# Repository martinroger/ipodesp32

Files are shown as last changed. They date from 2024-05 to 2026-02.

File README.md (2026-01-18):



# iPodESP32 : an iPod emulator for 2nd gen Minis

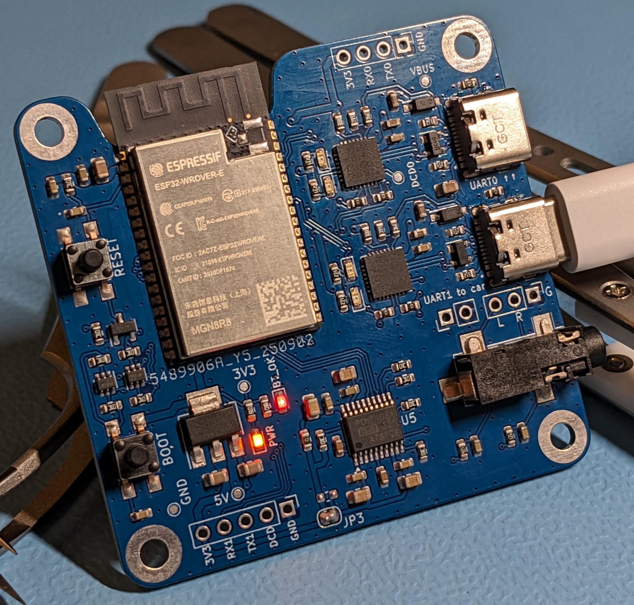
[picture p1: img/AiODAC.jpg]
AiO DAC board prototype


## CAVEAT
> [!WARNING]
> At the time of this commit, it has become apparent that the all CP2102 chips are not born equal. The hack consisting of spoofing a PL2303HX by overwriting the PID and VID on a CP2102 **only works on older versions**. I haven't yet managed to get it to work on CP2102N or CP2102-GM transceivers. Additionally, I haven't managed to get this hack to work on CP2104 or FTDI232R transceivers. For the time being, I would recommend holding off from ordering boards based on the designs in PCB unless you are certain you can source pre-2018 CP2102 chips.
> Work is happening on finding a solution, as the PL2303TA that would be the ideal candidate is hard to find in stock too.
> 
> **I may have found a practical solution by getting an ESP32S3 to spoof being a PL2303HX. Release v1.0.0 will introduce that solution !**

## Summary (TL;DR)

Second generation Minis (R56, R57, R58...) did not come with Bluetooth music streaming unless the Visual Boost or Mini Connected navigation option was selected (which wasn't hugely popular). 
Some of the later Minis (usually called LCI, or facelift Mini) started shipping with iPod support in the form of an USB receptacle, a 3.5mm AUX input and a special "Y-Cable". 

This repository is an attempt at bridging that gap with an ESP32 and a bag of tricks to provide **BT music streaming, retaining track data on the display and radio/steering wheel playback controls.**

## What is needed

Aside from a [Mini with a compatible radio head unit](https://github.com/martinroger/ipodesp32/wiki/How-to-identify-compatible-Minis) : 

- For the [full-DIY build](https://github.com/martinroger/ipodesp32/wiki/DIY-DAC%E2%80%90based-solution-(UDA1334A)) :
  - An ESP32 (not S3!) that has Bluetooth Classic or EDR support
  - A DAC (UDA1334 or PCM5102) breakout board
  - A CP2102 ~~or CP2104~~ breakout board with exposed DCD pin (no CP2102N or CP2102GM)
  - Jumper wires
  - Possibly some smaller hardware (resistors, capacitors) and a soldering iron

- For the Sandwich Carrier Board build, [follow this article](https://github.com/martinroger/ipodesp32/wiki/Sandwich-Carrier-Board-build)
- For the ESP32 AudioKit Top Hat build, [follow this other article](https://github.com/martinroger/ipodesp32/wiki/AudioKit-and-Haut%E2%80%90de%E2%80%90Forme-board)
- For the fancy ones out there wanting a small ESP32 A1S Mini, [it's here](https://github.com/martinroger/ipodesp32/wiki/ESP32%E2%80%90A1S%E2%80%90Mini-build)
- For the fancy but alternative-minded ones who also want an All-In-One, [it's there](https://github.com/martinroger/ipodesp32/wiki/ESP32%E2%80%90AiO-build)

## Alternative solutions

Over the year, some companies (mostly in China) have developped similar devices, such as the ones sold by **[Bovee](https://a.co/d/5lkZTkV)** or **[Gitank](https://thegitank.com/products/gitank-bluetooth-5-0-aptx-hd-adapter-with-y-cable-for-bmw-and-mini-cooper-usb-aux-ipod-iphone-music-interface-300b)**. The general principle is the same : a BT speaker is running an A2DP profile, while sufficient iPod-like communication is performed with the Mini to make it think there is an actual iPod connected.

I have had a very mixed bag of results with those, and it appeared to be even worse when using an Android phone, as the Playback/Synchronisation/Metadata seemed to be mostly reserved to iPhone users. Playback controls were also hit-and-miss.

## The iPodESP32 solution

Beyond the lame name, the solution proposed here does the following :

- Emulates an iPod Classic 5 - the U2 edition to be precise
- Passes song metadata from the phone/tablet (**Android or iOs**... or even others ?) regardless of what is playing the songs (Spotify remains the most tested to this date)
- Enables direct playback control from the radio interface, including steering wheel controls if present
- Auto-reconnects on ignition on, auto-pauses on ignition off
- Auto-pause and passes to whichever handsfree solution is present in case of phone call
- Provides many different interfaces for debug logging... because surely I didn't catch all them bugs
- Does not require any permanent modification of the car

## External (essential) libraries used

Respect where is due to the underlying libraries needed for this to work : 
- [AudioTools](https://github.com/pschatzmann/arduino-audio-tools)
- [ESP32-A2DP library](https://github.com/pschatzmann/ESP32-A2DP)
- [Arduino Audio Driver](https://github.com/pschatzmann/arduino-audio-driver)

## How to use it, and some tips

Although it should be pretty straightforward at this stage, to use this, you need to connect the USB with the modified VID/PID to the USB receptacle of the car, and the audio jack to the AUX input (with a male-male stereo cable, for example).

In its default configuration, the controller will wait for an established BT connection to a phone before it starts signalling to the vehicle that it is available. This is only necessary the first time a phone is connected to it, in other cases the controller will try to auto-reconnect.

Once the controller has established connection with the phone, it starts the handshake process with the head unit, and if all is good the Aux and USB options in the "Mode" source selector of the head unit are replaced by an "iPod" option. This normally takes a few seconds if the controller was just connected, so re-check after 10s if the iPod option is not available.
If it still doesn't come up, in some occasions it is necessary to disconnect the USB cable, wait 5-10 seconds and reconnect it and wait for the BT pairing to go through (check your phone!).

The Mini will try to automatically start playback once the iPod option is selected. Depending on your phone configuration, it may automatically open your favourite music player and start playing. In some cases it might be necessary to manually open a music player for things to get started. At this stage the display should update with the track info.

When you leave the car, the USB gets shut down after about 2 minutes (no risks of draining the battery) and normally the Mini negotiates a playback pause as the ignition is turned off...

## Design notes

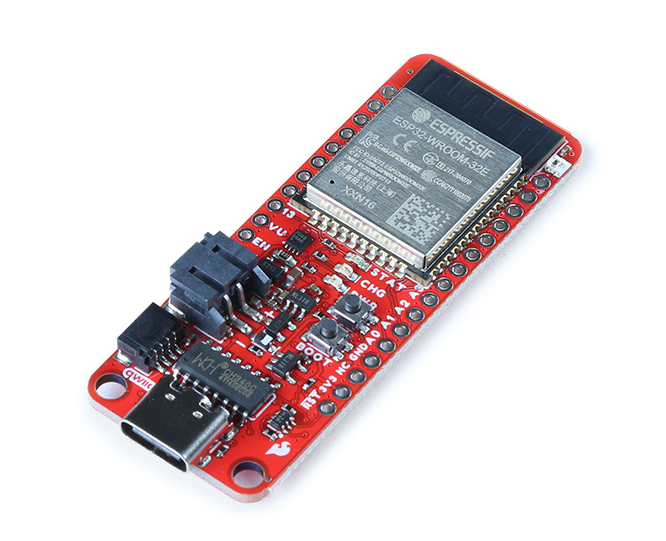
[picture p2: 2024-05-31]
img/SparkfunThingPlus.png

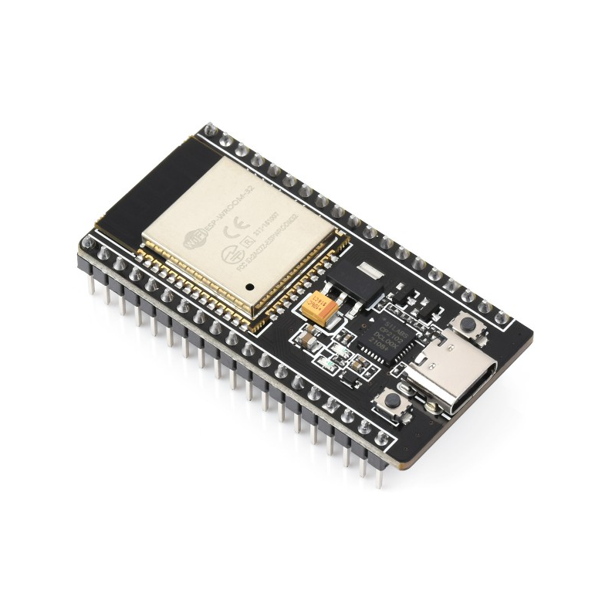
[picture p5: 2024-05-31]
img/nodeMCU32s.png

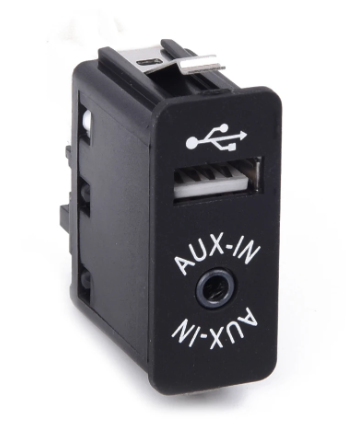
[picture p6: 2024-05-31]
img/usbAux.png

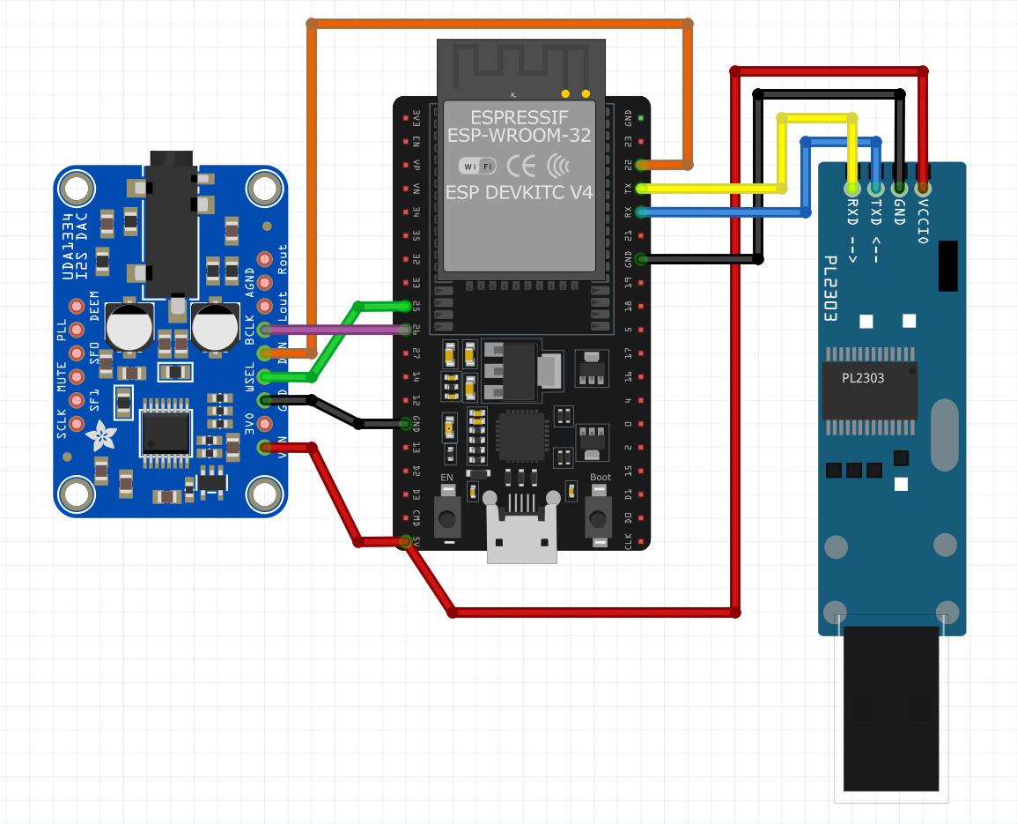
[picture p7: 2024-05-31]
img/routingDevKitCV4.png

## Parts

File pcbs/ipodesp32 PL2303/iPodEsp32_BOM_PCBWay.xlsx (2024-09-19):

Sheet: ipodesp32 PL2303
Reference | Value | Footprint | Datasheet | Description | Manufacturer_Name | Manufacturer_Part_Number | Mouser Part Number | Mouser Price/Stock | Qty
C1 | 4.7u | Capacitor_SMD:C_0603_1608Metric | https://mm.digikey.com/Volume0/opasdata/d220001/medias/docus/609/CL10A475KP8NNNC_Spec.pdf | CAP CER 4.7UF 10V X5R 0603 | Samsung Electro-Mechanics | CL10A475KP8NNNC |  |  | 1
C2 | 0.1u | Capacitor_SMD:C_0603_1608Metric | https://www.yageo.com/upload/media/product/productsearch/datasheet/mlcc/UPY-GPHC_X7R_6.3V-to-250V_24.pdf | CAP CER 0.1UF 16V X7R 0603 | Yageo | CC0603KRX7R7BB104 |  |  | 1
C3 | 10u | Capacitor_SMD:C_0805_2012Metric | https://connect.kemet.com:7667/gateway/IntelliData-ComponentDocumentation/1.0/download/datasheet/C0805C106K8PACTU | CAP CER 10UF 10V X5R 0805 | Kemet | C0805C106K8PAC7800 |  |  | 1
C4 | 1u | Capacitor_SMD:C_0603_1608Metric | https://mm.digikey.com/Volume0/opasdata/d220001/medias/docus/3584/CL10B105KP8NNNC_Spec.pdf | CAP CER 1UF 10V X7R 0603 | Samsung Electro-Mechanics | CL10B105KP8NNNC |  |  | 1
D1-D3 | 2.1V | LED_SMD:LED_0603_1608Metric | https://mm.digikey.com/Volume0/opasdata/d220001/medias/docus/858/LTST-C190GKT.pdf | LED GREEN CLEAR CHIP SMD | Lite-On Inc. | LTST-C190GKT |  |  | 3
IC1 | PL2303GS | SamacSys_Parts:SOIC127P600X170-8N |  | SOP-8_150mil USB ICs | Prolific | PL2303GS |  |  | 1
IC2 | 3678 | SamacSys_Parts:3678 | https://cdn-learn.adafruit.com/downloads/pdf/adafruit-i2s-stereo-decoder-uda1334a.pdf | Audio IC Development Tools Adafruit I2S Stereo Decoder - UDA1334A | Adafruit | 3678 |  |  | 1
J1 | USB_A | Connector_USB:USB_A_CNCTech_1001-011-01101_Horizontal | https://www.cnctech.us/pdfs/1001-011-01101_.pdf | CONN PLUG USB1.1 TYPEA 4P SMD RA | CNC Tech | 1001-011-01101 |  |  | 1
J2 | Conn_01x19_Pin | Connector_PinHeader_2.54mm:PinHeader_1x19_P2.54mm_Vertical | ~ |  |  |  |  |  | 1
J3 | Conn_01x05_Pin | Connector_PinHeader_2.54mm:PinHeader_1x05_P2.54mm_Vertical | ~ |  |  |  |  |  | 1
JP1 | TXD Route | Jumper:SolderJumper-3_P1.3mm_Bridged12_Pad1.0x1.5mm | ~ |  |  |  |  |  | 1
JP2 | RXD Route | Jumper:SolderJumper-3_P1.3mm_Bridged12_Pad1.0x1.5mm | ~ |  |  |  |  |  | 1
R2-R4 | 1K | Resistor_SMD:R_0603_1608Metric | https://www.yageo.com/upload/media/product/products/datasheet/rchip/PYu-RC_Group_51_RoHS_L_12.pdf | RES 1K OHM 1% 1/10W 0603 | Yageo | RC0603FR-071KL |  |  | 3
R5, R6 | 22 | Resistor_SMD:R_0603_1608Metric | https://www.yageo.com/upload/media/product/products/datasheet/rchip/PYu-RC_Group_51_RoHS_L_12.pdf | RES 22 OHM 1% 1/10W 0603 | Yageo | RC0603FR-0722RL |  |  | 2
U1 | ESP32-DevKitC | Espressif:ESP32-DevKitC | https://docs.espressif.com/projects/esp-idf/zh_CN/latest/esp32/hw-reference/esp32/get-started-devkitc.html |  |  |  |  |  | 1

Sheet: Sheet1
 |  |  | xxxx xxxx xxxxx xxPCS BOM (Sample Bill of Materials)
Item # | *Designator | *Qty | Manufacturer | *Mfg Part # | Description / Value | *Package/Footprint | Type | Your Instructions / Notes
1 | C1 | 1 | Samsung Electro-Mechanics | CL10A475KP8NNNC | CAP CER 4.7UF 10V X5R 0603 | Capacitor_SMD:C_0603_1608Metric | SMD
2 | C2 | 1 | Yageo | CC0603KRX7R7BB104 | CAP CER 0.1UF 16V X7R 0603 | Capacitor_SMD:C_0603_1608Metric | SMD
3 | C3 | 1 | Kemet | C0805C106K8PAC7800 | CAP CER 10UF 10V X5R 0805 | Capacitor_SMD:C_0805_2012Metric | SMD
4 | C4 | 1 | Samsung Electro-Mechanics | CL10B105KP8NNNC | CAP CER 1UF 10V X7R 0603 | Capacitor_SMD:C_0603_1608Metric | SMD
5 | D1-D3 | 3 | Lite-On Inc. | LTST-C190GKT | LED GREEN CLEAR CHIP SMD | LED_SMD:LED_0603_1608Metric | SMD
6 | IC1 | 1 | Prolific | PL2303GS | SOP-8_150mil USB ICs | SamacSys_Parts:SOIC127P600X170-8N | SMD
7 | J1 | 1 | CNC Tech | 1001-011-01101 | CONN PLUG USB1.1 TYPEA 4P SMD RA | Connector_USB:USB_A_CNCTech_1001-011-01101_Horizontal | DNS | DO NOT SOLDER, please supply
8 | R2-R4 | 3 | Yageo | RC0603FR-071KL | RES 1K OHM 1% 1/10W 0603 | Resistor_SMD:R_0603_1608Metric | SMD
9 | R5, R6 | 2 | Yageo | RC0603FR-0722RL | RES 22 OHM 1% 1/10W 0603 | Resistor_SMD:R_0603_1608Metric | SMD

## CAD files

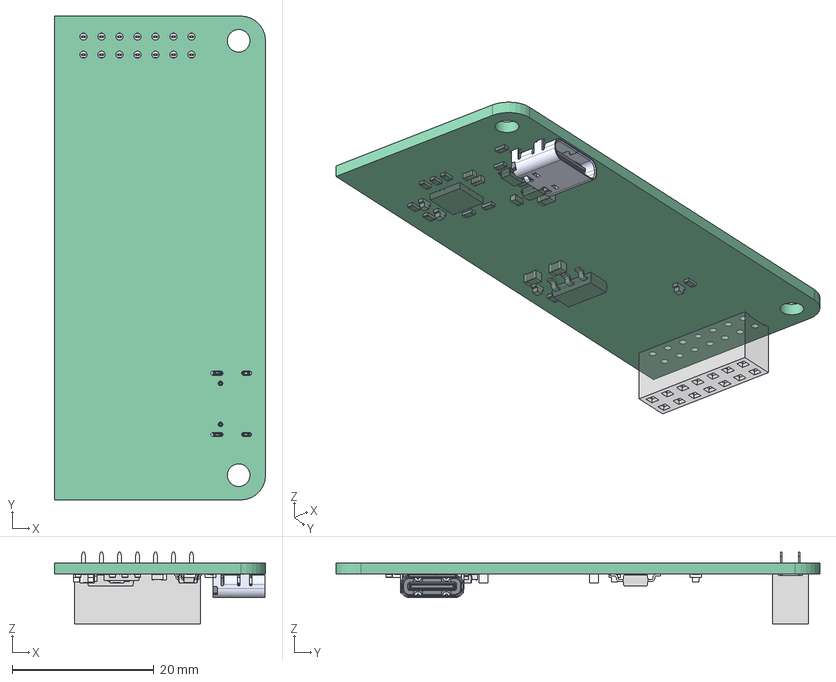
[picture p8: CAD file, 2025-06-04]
pcbs/hautDeForme/hautDeForme-hautDeForme.step
29.8 x 68.3 x 10.1 mm
Pcb_adfa
C14_C_0603_1608Metric_466b06563dad x 3
C6_C_0805_2012Metric_36fd2068b96d x 3
R26_R_0603_1608Metric_7708bdc434fe x 12
D9_LED_0603_1608Metric_46d654ef8e3e x 4
J1_PinSocket_2x07_P254mm_Vertical_6ab3e544b67c
U2_SOT_223_cc65569aa0fe
U4_QFN-28-1EP_5x5mm_Pitch0.5mm_e0a1b5ef8927
D14_D_SOD_123_b6459e2e886b
USB4105GFA_USB4105GFA
USB4105GFA_USB4105GFA001
USB4105GFA_USB4105GFA002
USB4105GFA_USB4105GFA003
USB4105GFA_USB4105GFA004
USB4105GFA_USB4105GFA005
USB4105GFA_USB4105GFA006
USB4105GFA_USB4105GFA007
USB4105GFA_USB4105GFA008
USB4105GFA_USB4105GFA009
USB4105GFA_USB4105GFA010
USB4105GFA_USB4105GFA011
USB4105GFA_USB4105GFA012
USB4105GFA_USB4105GFA013
USB4105GFA_USB4105GFA014
USB4105GFA_USB4105GFA015
USB4105GFA_USB4105GFA016
USB4105GFA_USB4105GFA017
USB4105GFA_USB4105GFA018
USB4105GFA_USB4105GFA019
USB4105GFA_USB4105GFA020
USB4105GFA_USB4105GFA021
USB4105GFA_USB4105GFA022
USB4105GFA_USB4105GFA023
USB4105GFA_USB4105GFA024
USB4105GFA_USB4105GFA025
USB4105GFA_USB4105GFA026
USB4105GFA_USB4105GFA027
USB4105GFA_USB4105GFA028
USB4105GFA_USB4105GFA029
USB4105GFA_USB4105GFA030
USB4105GFA_USB4105GFA031
USB4105GFA_USB4105GFA032
USB4105GFA_USB4105GFA033
USB4105GFA_USB4105GFA034
USB4105GFA_USB4105GFA035
USB4105GFA_USB4105GFA036
USB4105GFA_USB4105GFA037
USB4105GFA_USB4105GFA038
USB4105GFA_USB4105GFA039
USB4105GFA_USB4105GFA040
USB4105GFA_USB4105GFA041
USB4105GFA_USB4105GFA042
USB4105GFA_USB4105GFA043
D8_SOT_143_8c8184d03dee

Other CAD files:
pcbs/hautDeForme/hautDeForme.FCStd
pcbs/legacy boards/hautDeForme/hautDeForme.FCStd

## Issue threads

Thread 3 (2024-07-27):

PL2303 non-Gx are difficult to find and have the wrong PID

martinroger, 2024-07-27:
PL2303 Serial chips have become difficult to find. The latest variant this project is based upon, the PL2303Gx hasa different product ID (PID) of 23A3 and therefore is not recognized by the Boost CD unit.

Workarounds involve either rewriting the PID on the OTPRom (it works) or using a different chipset that has also an overwritable VID/PID.

martinroger, 2024-08-28:
Solution potentially found with the SiLab CP2102. Spoofing the VID and PID to look like a PL2303HX works, somehow !

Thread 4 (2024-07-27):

When skipping to the next song, the track info is not updated until the next skip

martinroger, 2024-07-27:
When actively skipping, the track info is not updated unless another fwd skip is requested OR the "Track" button is pressed.
Automatic change is not impacted

martinroger, 2024-08-28:
Will be addressed by specific PR

APF-MRoger, 2024-09-13:
Fixed in 50ea877a67728276d68b7e3371425ac8521d2902 initially but it broke the PREV/NEXT flip flopping because of a misconception around the prevXXX properties of espod and performing unjustified comparisons to try and determine NEXT/PREV moves when triggered from the phone.

First cleaned fix to be tested in ad4c92ea65b2d87a1674b790854c9f8f80d46cca

martinroger, 2024-09-19:
Pending Ack until new metadata seems to work OK. Fixed officially in 719ab09c6c69dd3a6eb89c550ffffab03b6c3533

Closed 2024-09-19.

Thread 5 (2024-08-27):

prevXXX character arrays for metadata are not updated

APF-MRoger, 2024-08-27:
prevXXX arrays are used for comparison but actually never updated so the comparison remains moot.

APF-MRoger, 2024-09-13:
prevXXX standalone arrays deprecated.
prevXXX property arrays of espod now used as a "previously playing track" info holders in case of rapid-firing requests during mini-triggered track changes.
**NO COMPARISON TO ASSESS IF THERE IS A SPONTANEOUS FWD/RWD TRACK CHANGE ANYMORE**

First official clean commit would be ad4c92e .

APF-MRoger, 2024-09-16:
Comparisons on prevXXX property arrays are now removed in 308ae70 so this issue should be closed.

Closed 2024-09-16.

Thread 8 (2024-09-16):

Track change using SetCurrentTrack need to be inhibited when there is a trackChangeAckPending

APF-MRoger, 2024-09-16:
When trackChangeAckPending is live, it is possible to still react to another current track change request. It might be necessary to inhibit those commands if there is a trackChangeAckPending when the command is received.

Also the trackChangeAckPending timeout should be reduced

martinroger, 2024-09-16:
trackChangeAckPending timeout shows that it should be doable in less than 600ms. However the 1100ms is still comfortable.

martinroger, 2024-09-19:
Issue seems irrelevant or a rare edge case. Closing for now.

Closed 2024-09-19.

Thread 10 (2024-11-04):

Receive and assess audiokit / ESP32 A1S board

martinroger, 2024-11-04:
Receive the Audiokit board, perform the following checks :

- [x] Flash via pins
- [x] Codec present on the board
- [x] UART interface VID/PID reprogrammability
- [ ] #15

martinroger, 2024-11-15:
- Codec is Es8388V1
- UART interface for UART0 is a Silabs CP2102. Checking if flashable via header.

martinroger, 2024-11-17:
To check :

- [ ] TX **and** RX capability of spoofed CP2102
- [ ] SD Card logging in appropriate branch. Resources : https://github.com/cyberman54/ESP32-Paxcounter/blob/master/src/sdcard.cpp

martinroger, 2024-11-26:
SD Card logging is proving to be an issue. SD card updating is OK.

Closed 2024-11-27.

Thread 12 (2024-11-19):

Move to pioarduino as other projects

martinroger, 2024-11-19:
There could be remnant issues with using the outdated framework. Move to https://github.com/pioarduino/platform-espressif32/releases/download/51.03.07/platform-espressif32.zip or 51.03.06

Closed 2024-11-27.

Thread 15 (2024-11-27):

SD Card local log implementation

martinroger, 2024-11-27:
Logging internal logs to the SD card is proving difficult as this is based on the Arduino framework. Plans are to move to IDF at some stage and use Arduino as components

Closed 2024-11-30.

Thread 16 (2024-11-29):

Loss of incoming Serial traffic after a few minutes

martinroger, 2024-11-29:
Using a CP2102 spoofing the VID/PID, incoming serial traffic seems sometimes lost. Not clear if SW or HW issue.

martinroger, 2024-11-29:
Indirectly related to #3 ?
To do :

- [ ] Check with actual PL2303HX if the incoming Rx is lost at HW or SW level, using a USB-UART bridge (FZero ?)
- [ ] Scan VIDs and PIDs to see which ones does the mini respond to with Serial
- [ ] Check the documentation for the PL2303HX Serial over USB implementation ? Same for the CP2102.

martinroger, 2024-12-04:
Communication still lost with genuine external PL2303HX on Serial0. Alternative ideas :

- [ ] Extend play_pos notification interval to 10s
- [ ] Refactor packet sender to use only one write()
- [ ] Async play_pos serial notification out of notification
- [ ] Use alternative Serial on 19-22
- [ ] No SD + GPIO15 muting ROM bootloader

martinroger, 2025-01-29:
Some improvements in commit e49873f1153c51d0e834b5febe3ff3d66e971a00 which partially links #24 and #23 to this.

Increasing the polling time seems to generally make things more stable, suggesting multiple things :

- At 19200 baud, with a 8N1 configuration, it takes 10 bit/transferred bytes. Practically this means that it's roughly a transfer time of 0.5ms/byte, not counting necessary breaks. In practice it must be slower than that. Setting a refresh polling rate of 5ms meant that there could be collisions on the output of the TX function if called in two places at the same time. Additionally it probably over-polls the incoming Serial for any message longer than 10 bytes (which can happen reasonably often). **Serial silence is golden !**
- AVRC and A2DP callbacks are reasonably high priority (15), Serial calls are in theory highest (24) but are contained in functions that are inheriting from `loop()`, which is lowest (1). Meaning it is possible that it stretches the inter-byte time, or even worse, starts weaving Serial flushes in-between one another.

There are still some issues at 50ms interval rate, and this is untested with AVRC/A2DP notifications.

One solution could be to manipulate the methods of the espod class to have higher priorities, however this would just mumble the interactions. It is preferrable to proceed like follows :

- Two FreeRTOS Queues : one for RX messages to be processed, populated by a relatively low priority listener Task (lower than 15) as the Serial Buffer is large enough and it can be interrupted, and another Queue for TX function, which is higher priority in order not to be interrupted (but lower polling rate), like 50ms minimum.
- One RX task as above that progressively consolidates an incoming Buffer and eventually turns it into a message Queue.
- One Processing task that churns incoming RX messages in the rxQueue, and eventually releases new messages in the txQueue. It can be low priority but possibly not too low to avoid buffer clogging on the RX side. The question of Timer tasks has to be clarified, like the delayed Ack (possibly requiring semaphores or mutex)
- One -dumb- but uninterruptible TX task, that checks the TXQueue and sends what is in it. Possibly with multiple yields in and a mutex if it doesn't work.

Could it be possible with binary semaphores and mutexes instead of queues ? Probably, as the Serial buffer works a bit like a queue. Am I smart enough to make that happen ? I doubt it :D

martinroger, 2025-02-15:
Lots of gibberish in my previous analysis. Now able to run very aggressive timings with 144e74bca5b9c45a92b76c262e441f97527dc655 with good stability, **as long as the UART DCD signal is active (low) !**

In branch `[taskCtrl+asyncMeta+hrtbeat](https://github.com/martinroger/ipodesp32/compare/taskCtrl%2BasyncMeta%2Bhrtbeat)` we are trying to introduce a SW solution to avoid having to physically control the DCD pin because it is not easily accessible on the board itself, with commit 8962710bfd0159655eb789cc2ad41405db3dd8fd.

APF-MRoger, 2025-02-17:
The heartbeat trick does not work (or at least not if sent every 10s). The branch will be left in place but no further commit and will become stale.

martinroger, 2025-02-17:
Confirmed that DCD pin grounded on a CP2102 with spoofed PID and VID seems to work.

APF-MRoger, 2025-05-28:
Confirmed DCD trick **and bulking 5V capacitance** seems to work 99% of the time. Should be closed with #33 .

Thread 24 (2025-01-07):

Move Serial activity away from callbacks regarding notifications

martinroger, 2025-01-07:
Try flags to process information and send Serial only OUT of notification callbacks.

martinroger, 2025-01-21:
Commit 5871031230cd438b8592953082529b97171f3ab8 does not resolve the issue, and actually somehow breaks the metadata refresh.
Theory :

- SD logger calls to write might make it more unstable
- Possible conflict with the Serial calls to the head unit
- There is no control of the tasks/threads between the A2DP/AVRC, I2S, SD writes and the Serial writes. Could this be part of the disconnection issue. Might be interesting moving to a stricter Task/thread control to avoid mutual interrupts

martinroger, 2025-02-02:
Idea : use queue.

martinroger, 2025-02-15:
Getting ready for closure in #31

APF-MRoger, 2025-06-04:
Done with #33

Closed 2025-06-04.

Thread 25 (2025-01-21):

Implement stricter task partitioning between Serial and A2DP/I2S and SD

martinroger, 2025-01-21:
There is a potential concurrency issue between the Serial.xxx calls and the rest of the routines running in the back, including when the SD logger is activated. One solution is to make sure that Tasks are clearly assigned to Cores and clearly prioritised.

martinroger, 2025-02-15:
Tasks and Timers added in taskControl branch and its children. Ultimately this is unlikely to have been the issue, but rather a timeout from the Mini side. Trying two strategies now :
- Hard-grounding the DCD pin to ground (seems to work)
- Sending a dummy L0x00 request to the mini every 10s to see if it resets any timeout

Closed 2025-02-15.

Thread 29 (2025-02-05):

Queuing from Timer end callback creates a prohibited load

martinroger, 2025-02-05:
At the end of the timer, queuing to the txQueue creates a core panic.

APF-MRoger, 2025-02-05:
be937d030879a19a640b72b3dfd194285c192eaa for tentative fix, separate queue from ISR

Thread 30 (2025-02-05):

Double Ack after Ack Pending on track change if metadata has not come in fast enough

martinroger, 2025-02-05:
If new metadata has not cleared the trackChangeAckPending quickly enough and the timeout is triggered (1100ms currently) there can be an accidental double Ack. Here is an example :

```
[141115][I][esPod.cpp:1015] processLingo0x04(): [esPod] CMD 0x0029 PlayControl req: 0x03 vs playStatus: 0x01
[141125][I][esPod.cpp:1056] processLingo0x04(): [esPod] Prev. index 1 New index 0 Tracklist pos. 2 Pending Meta 1 Timestamp: 141125 --> EXPLICIT NEXT TRACK
[141141][I][esPod.cpp:1512] L0x04_0x01_iPodAck(): [esPod] Ack 0x06 to command 0x0029 Numfield: 1100
[141194][I][BluetoothA2DPSink.cpp:747] av_notify_evt_handler(): [BT_AV] Play position changed: 112628-ms
[141217][I][BluetoothA2DPSink.cpp:791] av_hdl_avrc_evt(): [BT_AV] AVRC passthrough rsp: key_code 0x4b, key_state 0
[141252][I][main.cpp:294] playStatusHandler(): [A2DP_CB] A2DP_NEXT
[141286][I][BluetoothA2DPSink.cpp:791] av_hdl_avrc_evt(): [BT_AV] AVRC passthrough rsp: key_code 0x4b, key_state 1
[142240][I][BluetoothA2DPSink.cpp:747] av_notify_evt_handler(): [BT_AV] Play position changed: 710-ms
[142254][I][esPod.cpp:1489] L0x04_0x01_iPodAck(): [esPod] Ack 0x00 to command 0x0029
[143274][I][BluetoothA2DPSink.cpp:747] av_notify_evt_handler(): [BT_AV] Play position changed: 1746-ms
[144327][I][BluetoothA2DPSink.cpp:747] av_notify_evt_handler(): [BT_AV] Play position changed: 2795-ms
[144736][I][BluetoothA2DPSink.cpp:747] av_notify_evt_handler(): [BT_AV] Play position changed: 3211-ms
[144806][I][BluetoothA2DPSink.cpp:796] av_hdl_avrc_evt(): [BT_AV] AVRC metadata rsp: attribute id 0x1, Intro feat. Stalley
[144817][I][main.cpp:182] avrc_metadata_callback(): [AVRC_CB] Title rxed, ACK pending, trackTitleUpdated to Intro feat. Stalley
[144831][I][BluetoothA2DPSink.cpp:796] av_hdl_avrc_evt(): [BT_AV] AVRC metadata rsp: attribute id 0x2, Flume, Stalley
[144843][I][main.cpp:149] avrc_metadata_callback(): [AVRC_CB] Artist rxed, ACK pending, artistNameUpdated to Flume, Stalley
[144856][I][BluetoothA2DPSink.cpp:796] av_hdl_avrc_evt(): [BT_AV] AVRC metadata rsp: attribute id 0x4, Flume (Deluxe Edition)
[144870][I][main.cpp:117] avrc_metadata_callback(): [AVRC_CB] Album rxed, ACK pending, albumNameUpdated to Flume (Deluxe Edition)
[144883][I][BluetoothA2DPSink.cpp:796] av_hdl_avrc_evt(): [BT_AV] AVRC metadata rsp: attribute id 0x40, 234146
[144895][I][main.cpp:219] avrc_metadata_callback(): [AVRC_CB] Duration rxed, ACK pending, trackDurationUpdated to 234146
[144908][I][main.cpp:247] avrc_metadata_callback(): [AVRC_CB] Artist+Album+Title+Duration +++ ACK Pending 0x29
        Pending duration: 0
[144922][I][esPod.cpp:1489] L0x04_0x01_iPodAck(): [esPod] Ack 0x00 to command 0x0029
[144932][I][main.cpp:250] avrc_metadata_callback(): [AVRC_CB] trackChangeAckPending reset to 0x00
[144942][I][main.cpp:256] avrc_metadata_callback(): [AVRC_CB] Artist+Album+Title+Duration : True -> False
```

martinroger, 2025-02-06:
Tentative fix in b8a9cb344ebcb970e56edc268eb22ed62d65b50d

Closed 2025-02-15.

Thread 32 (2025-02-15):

Design simplified Audiokit/LyraT board

martinroger, 2025-02-15:
Given that the large amount of peripherals on the Audiokit board are unused, maybe it would be better to copy a slimmed down version of the LyraT or AudioKit ?

martinroger, 2025-02-17:
Replaced by #34

Closed 2025-02-17.

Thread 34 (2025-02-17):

Create/modify PCBs to offer control of the DCD pin

martinroger, 2025-02-17:
- [x] Modify an AudioKit PCB
- [x] Create carrier board for "sandwich" implementation
- [x] Create standalone PCB

APF-MRoger, 2025-04-10:
Done in branch 32, will be integrated in #33

Closed 2025-04-10.

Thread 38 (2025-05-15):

Library compatibility tracking

APF-MRoger, 2025-05-15:
Commit 396cd43445c918b421badf7b288807d9891f2b66

OK :
|-- ESP32-A2DP @ 1.8.7+sha.b6a20dd
|-- audio-tools @ 1.1.0+sha.036645b
|-- audio-driver @ 0.1.2+sha.993248c

APF-MRoger, 2025-05-15:
Commit : 4e8b470e0b78374e47c078a42a8064976b8e7be9

OK :
|-- ESP32-A2DP @ 1.8.7+sha.f275b82
|-- audio-tools @ 1.1.1+sha.710fe3f
|-- audio-driver @ 0.1.3+sha.7c07c36

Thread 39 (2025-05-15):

Expose DCD pin as easy-to-solder pad

martinroger, 2025-05-15:
For non-BMW applications, it might be easier to expose the DCD pin as a through-hole pad.

APF-MRoger, 2025-05-26:
Done as of e5afc75e4cf8b15366bb625a20f870dff8392412

Closed 2025-05-26.

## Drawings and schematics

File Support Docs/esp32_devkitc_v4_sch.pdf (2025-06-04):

# ESP32 Module Power Supply

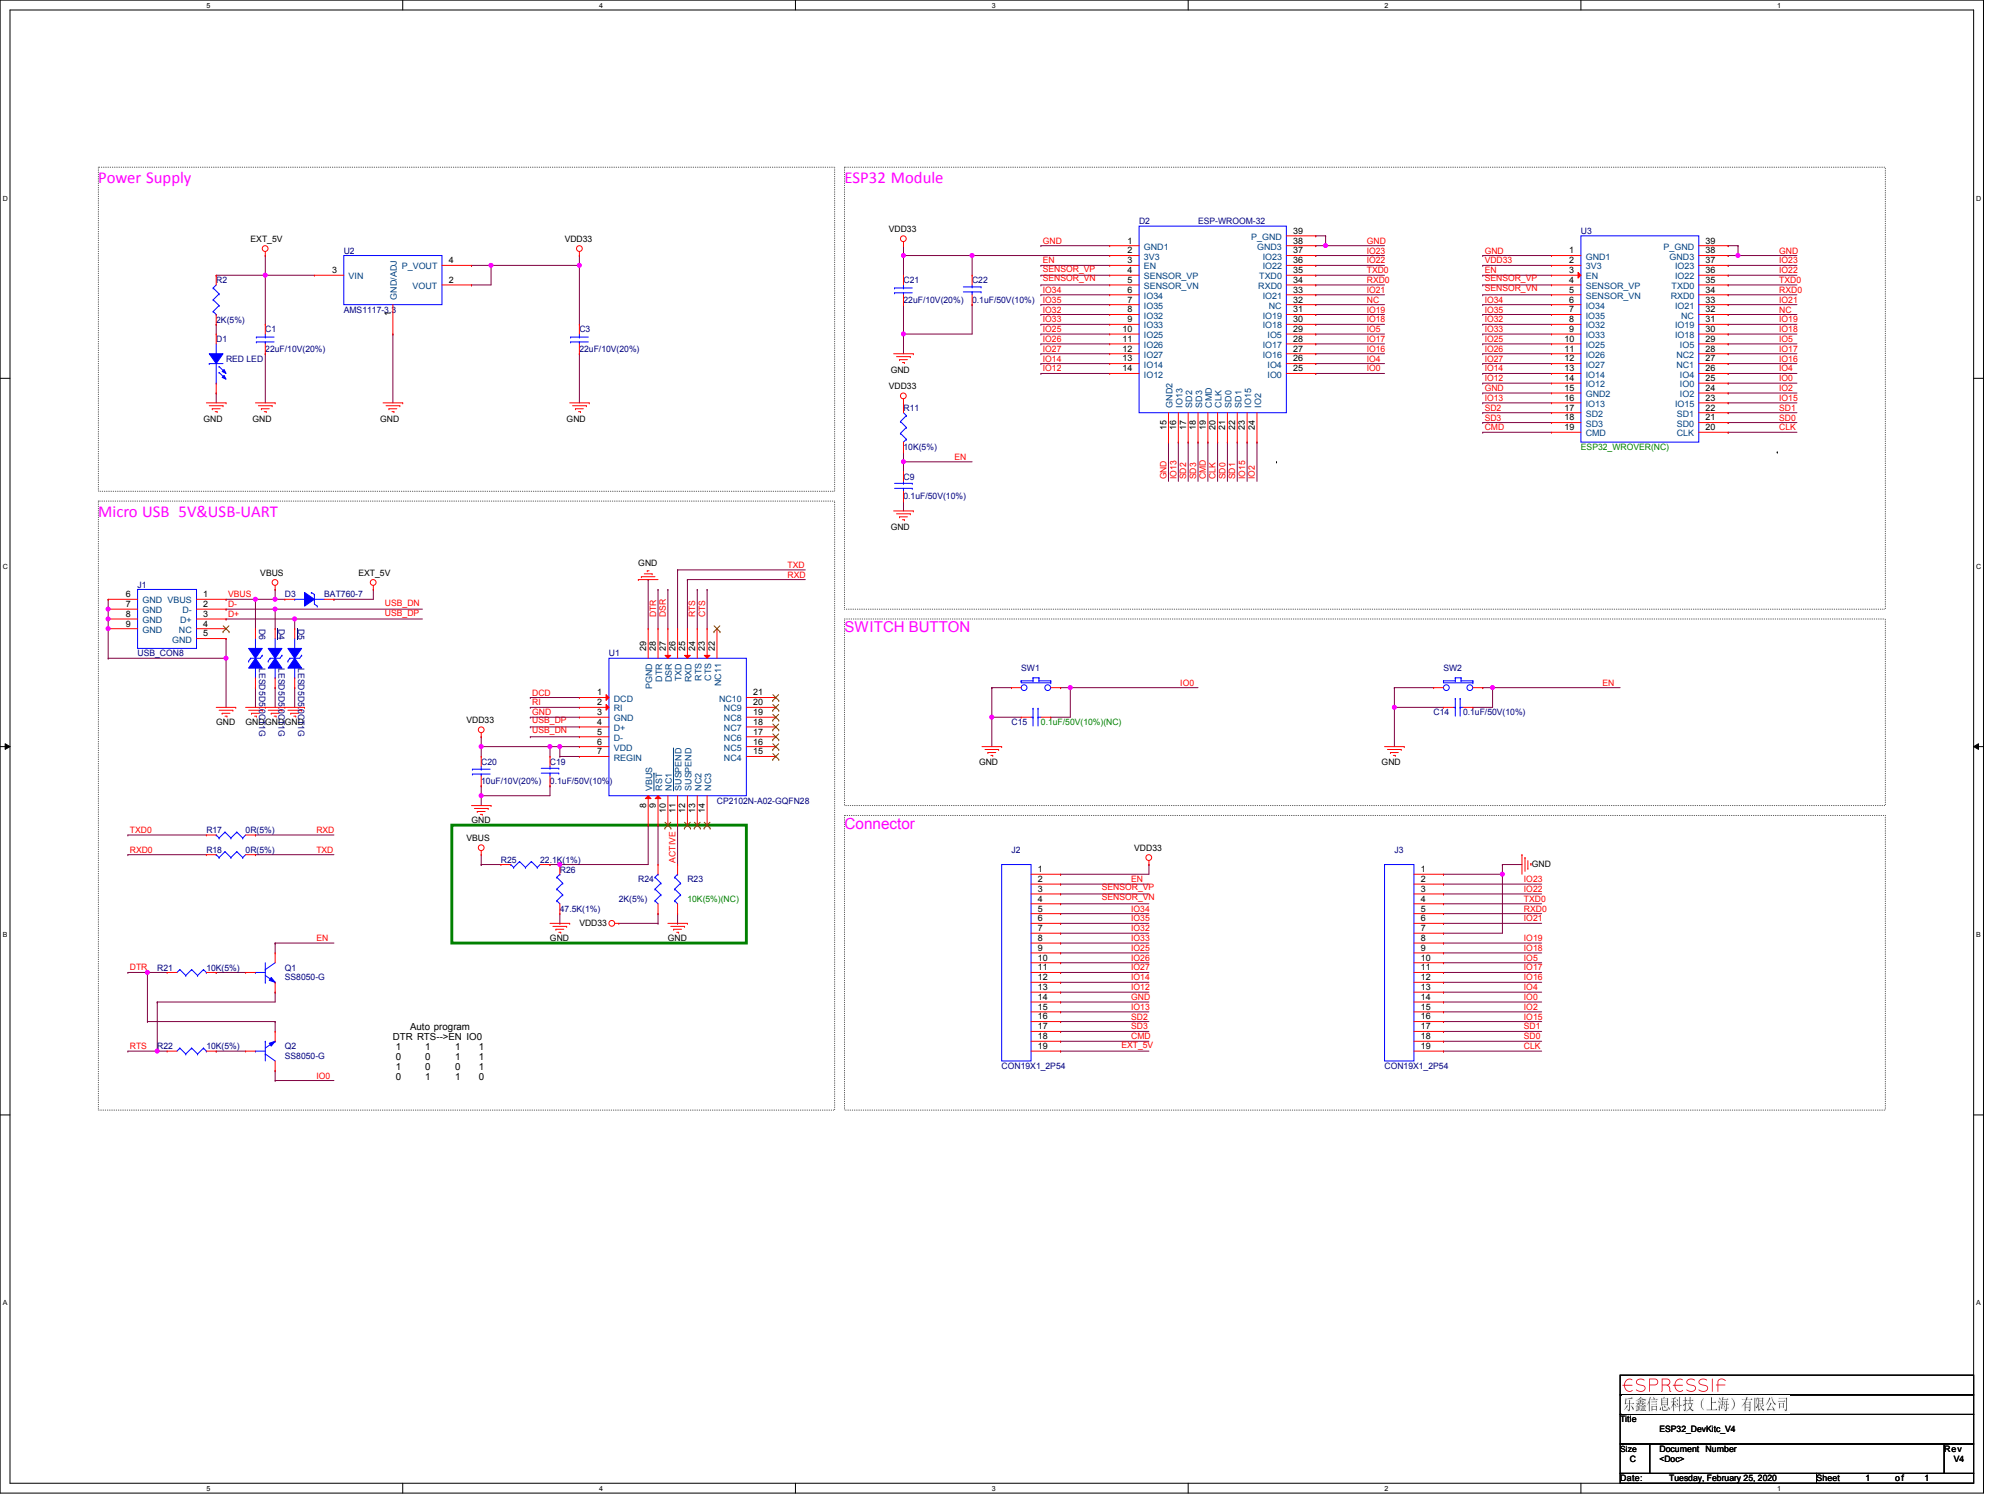
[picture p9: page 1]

Micro USB 5V&USB-UART

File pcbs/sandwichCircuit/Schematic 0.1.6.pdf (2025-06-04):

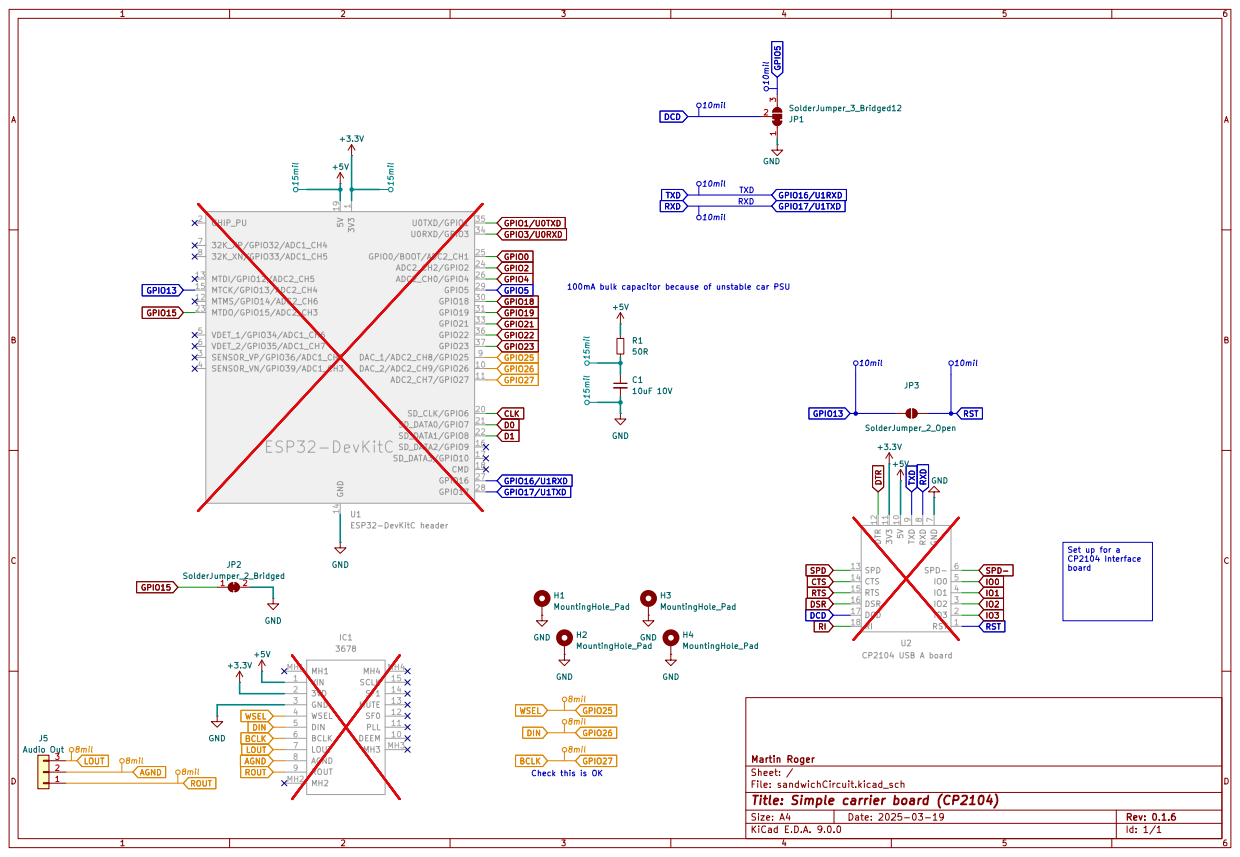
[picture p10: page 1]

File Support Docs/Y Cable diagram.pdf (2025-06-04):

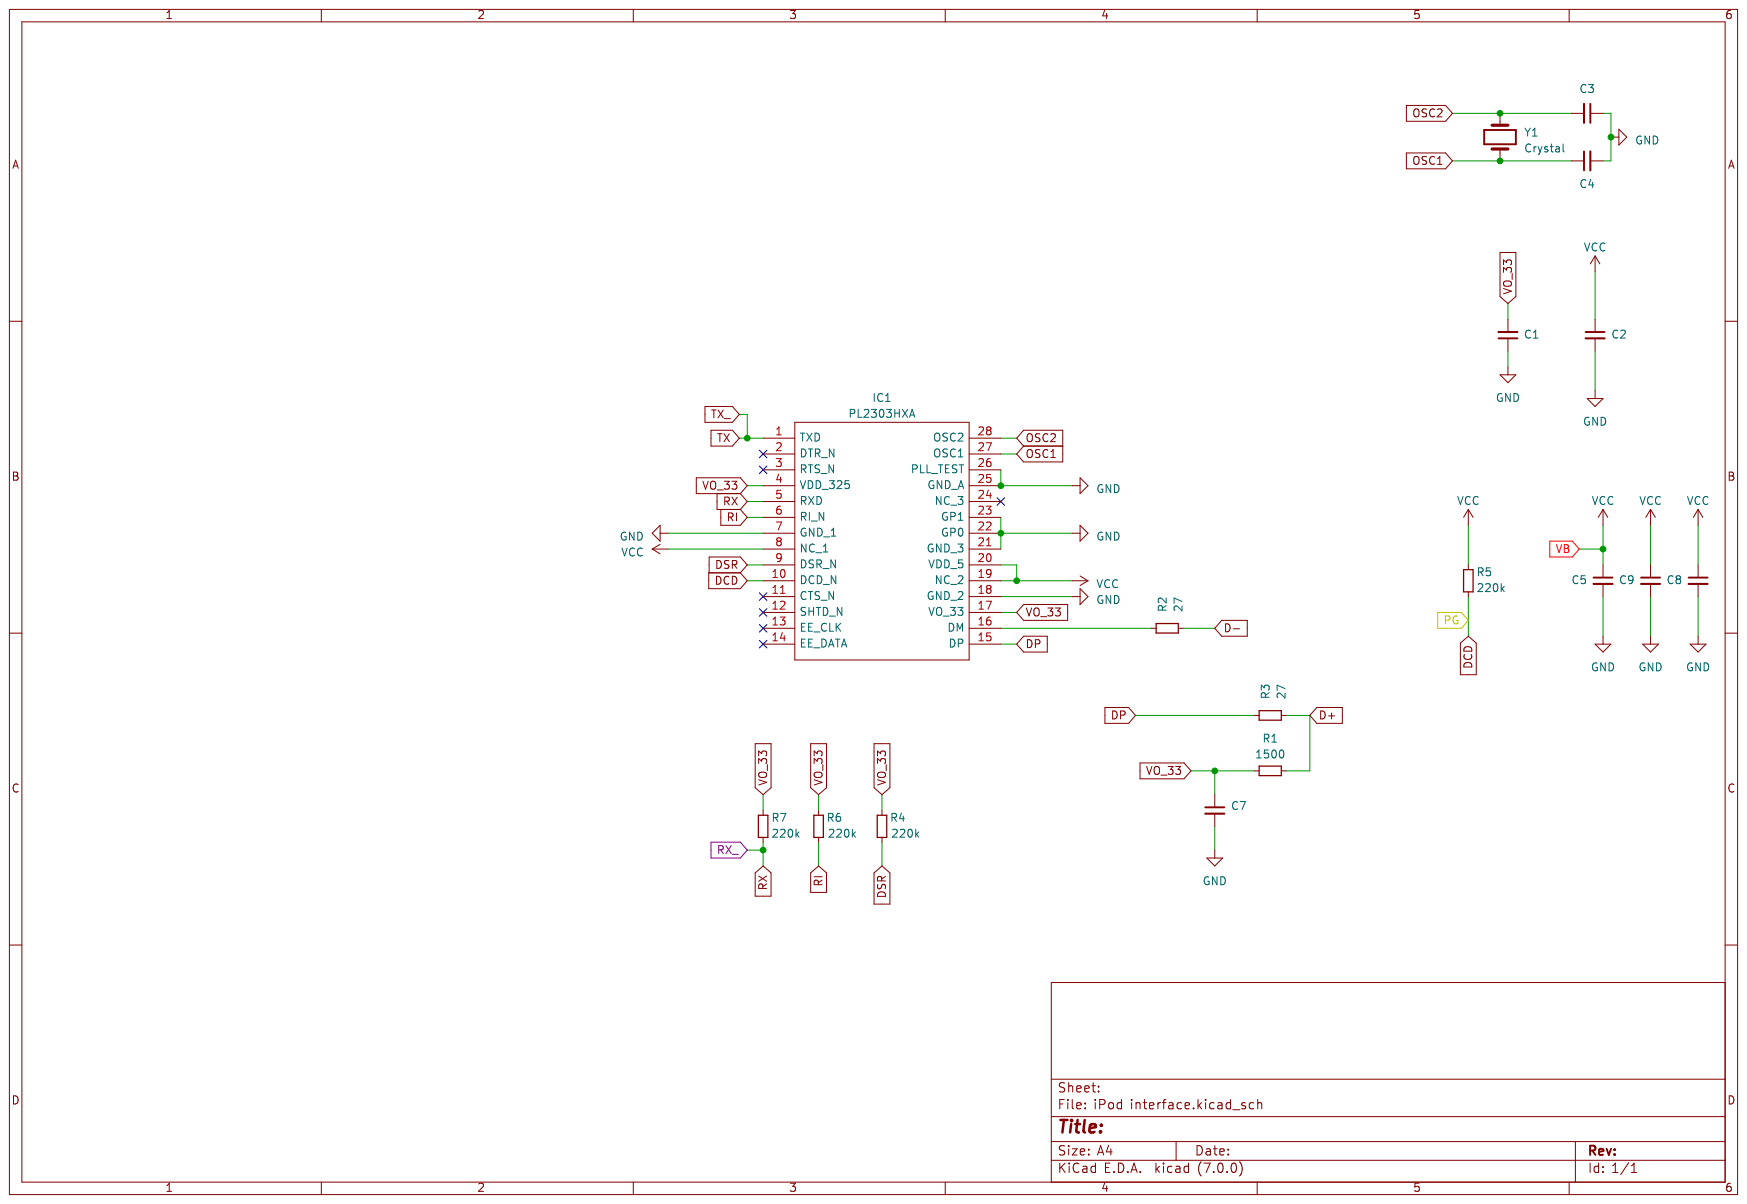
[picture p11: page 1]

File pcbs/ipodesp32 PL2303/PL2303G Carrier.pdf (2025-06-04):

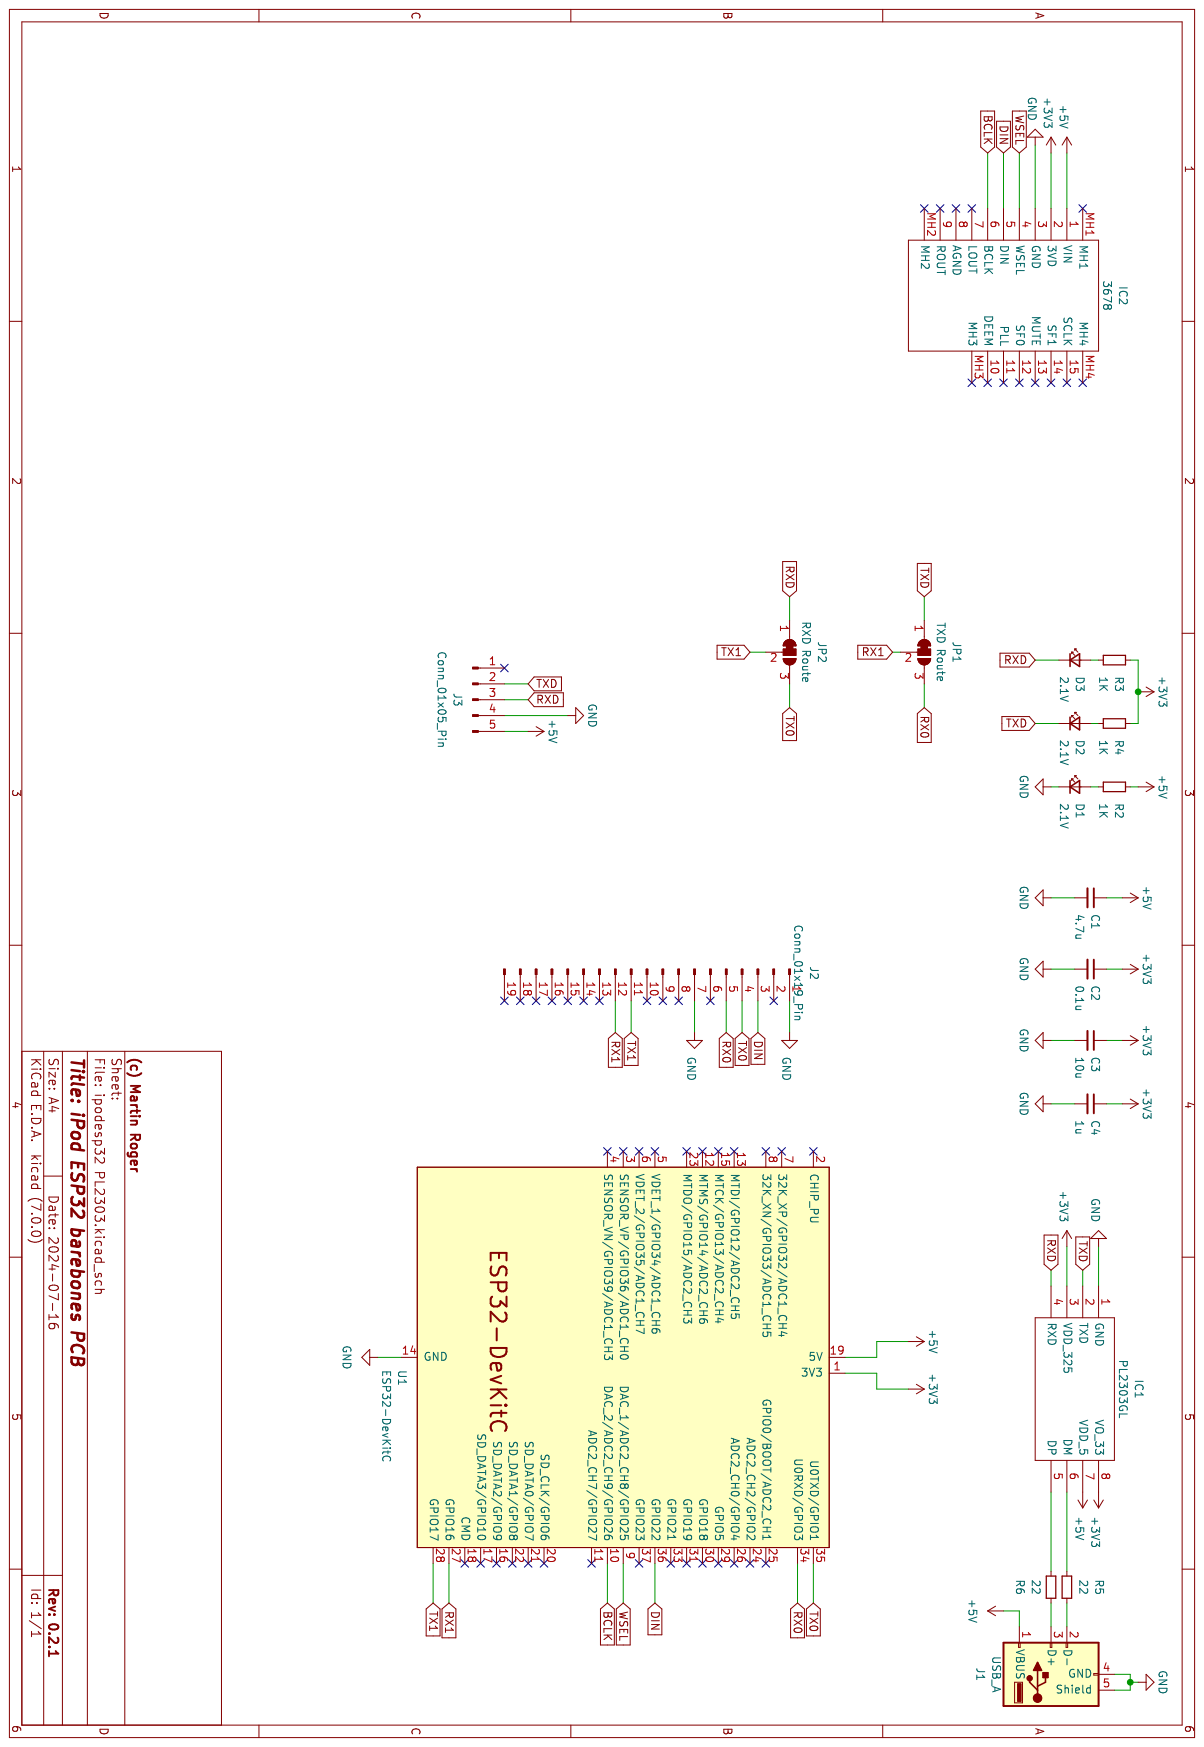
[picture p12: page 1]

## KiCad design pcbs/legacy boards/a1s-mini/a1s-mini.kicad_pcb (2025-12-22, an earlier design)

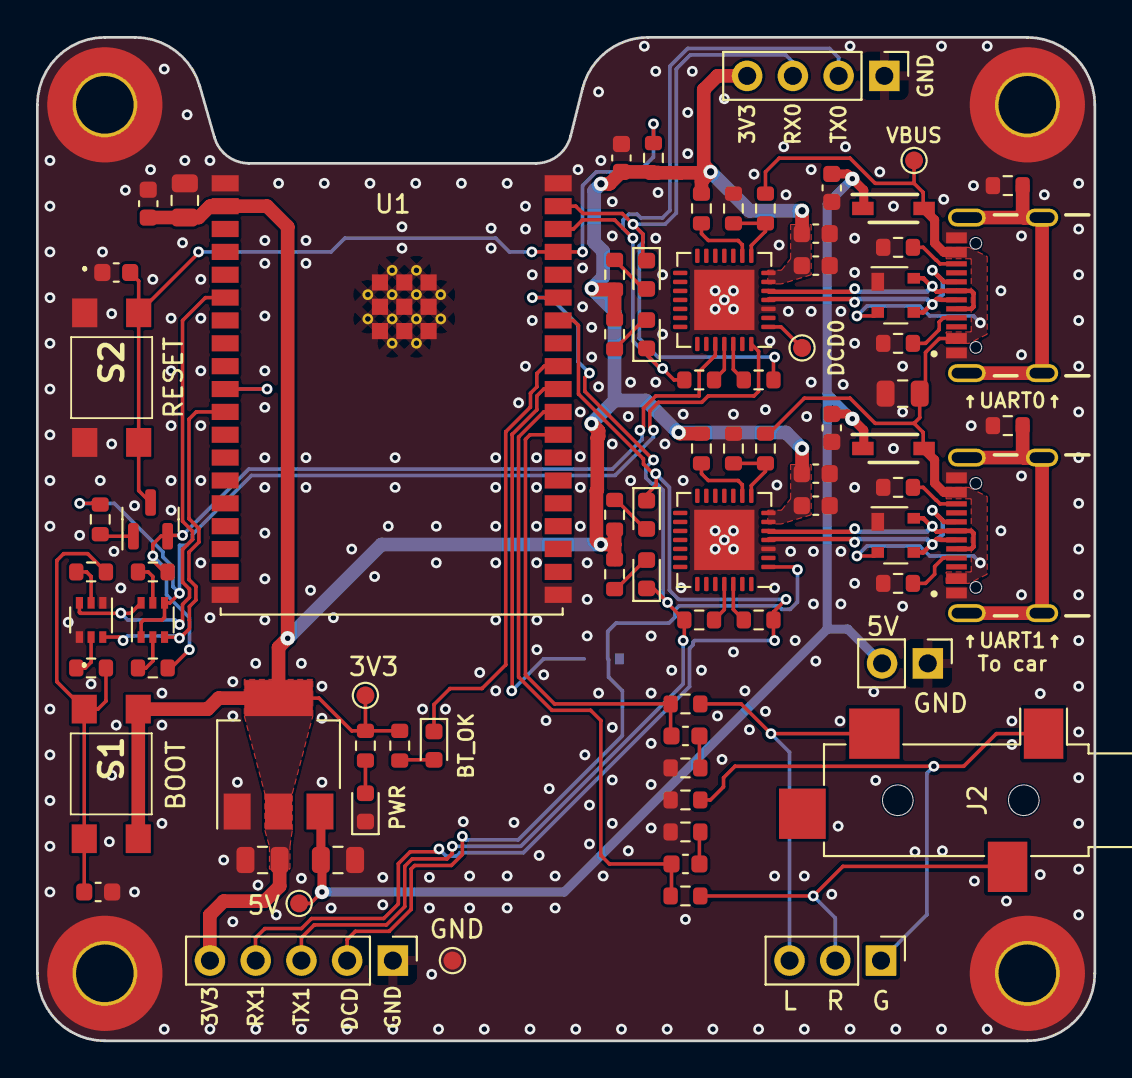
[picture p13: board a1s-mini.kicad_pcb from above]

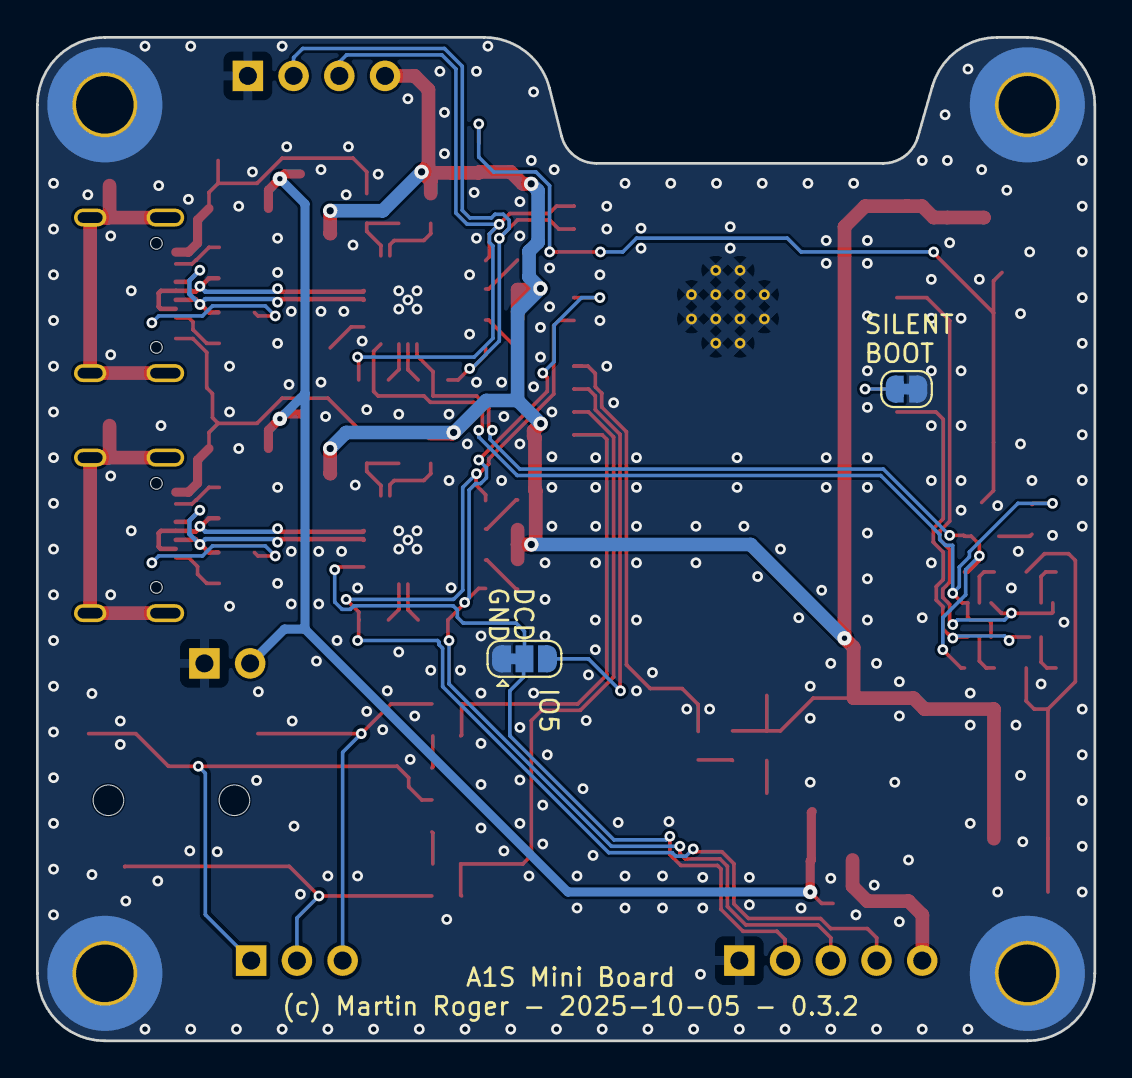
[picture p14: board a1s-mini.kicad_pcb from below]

Board: 2 copper layers, 58.8 x 55.7 mm, 86 parts (2 on the bottom side), 55 nets.

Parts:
3V1, 5V1: TestPoint_Small; TestPoint_Pad_D1.0mm
C1, C3, C4, C5, C8, C9, C11, C14: 0.1uF 50V; C_0603_1608Metric
C2, C6, C7, C16: 22uF 10V; C_0805_2012Metric
C10, C12, C13, C15: 10uF 10V; C_0603_1608Metric
D1, D2, D9, D11: 2.1V G 10mA; LED_0603_1608Metric
D5: 2.1V O 10mA; LED_0603_1608Metric
D6: 2V R 10mA; LED_0603_1608Metric
D7, D8: SP0503BAHTG; SOT-143
D10, D14: 1N5819HW-7-F; SOD3716X145N
DCD1: TestPoint_Small; TestPoint_Pad_D1.0mm
GND1: TestPoint_Small; TestPoint_Pad_D1.0mm
H1, H2, H3, H4: MountingHole_Pad; MountingHole_3.2mm_M3_Pad_TopBottom
J1: UART1; PinHeader_1x05_P2.54mm_Vertical
J2: SJ-3524-SMT-TR-PI; Jack_3.5mm_CUI_SJ-3524-SMT_Horizontal
J3: Audio Out; PinHeader_1x03_P2.54mm_Vertical
J4: UART0; PinHeader_1x04_P2.54mm_Vertical
J5, J6: USB4105-GF-A; GCT_USB4105-GF-A
J7: 5V; PinHeader_1x02_P2.54mm_Vertical
JP1: SolderJumper_3_Bridged12; SolderJumper-3_P1.3mm_Bridged12_RoundedPad1.0x1.5mm
JP2: SolderJumper_2_Bridged; SolderJumper-2_P1.3mm_Bridged_RoundedPad1.0x1.5mm
Q3: BC818; SOT-23
Q4, Q6: MBT3904DW1; SOT-363_SC-70-6
R1, R2, R5, R6, R34, R35: 1K 1%; R_0603_1608Metric
R7, R12, R13, R14, R32, R33: 10K 1%; R_0603_1608Metric
R8, R9: 22R 1%; R_0603_1608Metric
R10, R11, R18, R19, R21, R26, R27, R29, R31: 0R; R_0603_1608Metric
R15, R23: 22.1K 1%; R_0603_1608Metric
R16, R24: 47.5K 1%; R_0603_1608Metric
R17, R25: 2K 1%; R_0603_1608Metric
R20, R22, R28, R30: 5.1K 1%; R_0603_1608Metric
S1, S2: TL3305BF260QG
U1: ESP32 A1S; ESP32-A1S
U2: AZ1117CH-3.3TRG1; SOT-223-3_TabPin2
U3: CP2102N; QFN-28-1EP_5x5mm_P0.5mm_EP3.35x3.35mm
U4: CP2102-GM; QFN-28-1EP_5x5mm_P0.5mm_EP3.35x3.35mm
VBUS1: TestPoint_Small; TestPoint_Pad_D1.0mm

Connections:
+3.3V: 3V1.1, C1.2, C2.2, C3.2, C7.2, C10.2, C11.2, C13.2, C14.2, J1.5, J4.4, R1.1, R2.1, R5.1, R6.1, R7.1, R17.1, R25.1, R34.1, R35.1, S1.3, S1.4, U1.2 (3V3), U2.2 (VO), U3.6 (VDD), U3.7 (VREGIN), U4.6 (VDD), U4.7 (VREGIN)
+5V: 5V1.1, C6.2, C12.2, C15.2, D10.1, D14.1, J7.2, U2.3 (VI)
/CP2102N_0/D+: D7.3 (K), J5.A6 (DP1), J5.B6 (DP2), U3.4 (D+)
/CP2102N_0/D-: D7.4 (K), J5.A7 (DN1), J5.B7 (DN2), U3.5 (D-)
/CP2102N_0/DCD: DCD1.1, U3.1 (~DCD)
/CP2102_1/D+: D8.3 (K), J6.A6 (DP1), J6.B6 (DP2), U4.4 (D+)
/CP2102_1/D-: D8.4 (K), J6.A7 (DN1), J6.B7 (DN2), U4.5 (D-)
/CP2102_1/DCD: J1.2, JP1.2 (C), U4.1 (~DCD)
AGND: J2.S, J3.1, R31.1
DTR0: Q6.1 (E1), Q6.4 (E2), R12.1, U3.28 (~DTR)
EN: C8.2, Q3.3 (C), R7.2, S2.3, S2.4, U1.35 (EN)
GND: C1.1, C2.1, C3.1, C6.1, C7.1, C8.1, C9.1, C10.1, C11.1, C12.1, C13.1, C14.1, C15.1, C16.1, D5.1 (K), D7.1 (A), D8.1 (A), GND1.1, H1.1, H2.1, H3.1, H4.1, J1.1, J4.1, J5.A1_B12 (GND), J5.B1_A12 (GND__1), J6.A1_B12 (GND), J6.B1_A12 (GND__1), J7.1, JP1.1 (A), JP2.2 (B), Q4.1 (E1), Q4.4 (E2), R8.2, R9.2, R16.2, R20.1, R21.2, R22.2, R24.2, R28.1, R29.2, R30.2, R31.2, S2.1, S2.2, U1.1 (GND), U1.19 (GND), U1.20 (GND), U1.38 (GND), U1.39 (GND), U2.1 (GND), U3.3 (GND), U3.29 (GND), U4.3 (GND), U4.29 (GND)
HPOUTL: C4.2, R10.1, U1.27 (HPOUTL)
HPOUTR: C5.2, R11.1, U1.28 (HPOUTR)
IO0: Q4.3 (C2), Q6.6 (C1), U1.6 (IO0)
IO2: Q4.6 (C1), Q6.3 (C2), U1.11 (IO2)
IO5: JP1.3 (B), U1.29 (IO5)
IO18: D6.1 (K), U1.30 (IO18)
LOUT: J2.T, J3.3, R10.2
unnamed: C4.1, R8.1
unnamed: C5.1, R9.1
unnamed: C9.2, R32.1, R33.1, S1.1, S1.2
unnamed: D1.2 (A), R1.2
unnamed: D2.2 (A), R2.2
unnamed: D5.2 (A), R5.2
unnamed: D6.2 (A), R6.2
unnamed: D9.2 (A), R34.2
unnamed: D11.2 (A), R35.2
unnamed: J5.A5 (CC1), R20.2
unnamed: J5.B5 (CC2), R22.1
unnamed: J5.SH1 (SHELL_GND), J5.SH2 (SHELL_GND__1), J5.SH3 (SHELL_GND__2), J5.SH4 (SHELL_GND__3), R21.1
unnamed: J6.A5 (CC1), R28.2
unnamed: J6.B5 (CC2), R30.1
unnamed: J6.SH1 (SHELL_GND), J6.SH2 (SHELL_GND__1), J6.SH3 (SHELL_GND__2), J6.SH4 (SHELL_GND__3), R29.1
unnamed: JP2.1 (A), U1.10 (IO15)
unnamed: Q3.1 (B), R12.2
unnamed: Q4.2 (B1), R33.2
unnamed: Q4.5 (B2), R32.2
unnamed: Q6.2 (B1), R13.2
unnamed: Q6.5 (B2), R14.2
unnamed: R19.1, U3.25 (RXD)
unnamed: R18.1, U3.26 (TXD)
unnamed: R15.2, R16.1, U3.8 (VBUS)
unnamed: R17.2, U3.9 (~RST)
unnamed: R27.1, U4.25 (RXD)
unnamed: R26.1, U4.26 (TXD)
unnamed: R23.2, R24.1, U4.8 (VBUS)
unnamed: R25.2, U4.9 (~RST)
ROUT: J2.R, J3.2, R11.2
RTS0: Q3.2 (E), R13.1, R14.1, U3.24 (~RTS)
RXD0: D1.1 (K), J4.3, R18.2, U1.37 (RXD0)
RXD1: D9.1 (K), J1.4, R26.2, U1.32 (IO19)
TXD0: D2.1 (K), J4.2, R19.2, U1.36 (TXD0)
TXD1: D11.1 (K), J1.3, R27.2, U1.33 (IO22)
VBUS: C16.2, D7.2 (K), D8.2 (K), D10.2, D14.2, J5.A4_B9 (VBUS), J5.B4_A9 (VBUS__1), J6.A4_B9 (VBUS), J6.B4_A9 (VBUS__1), R15.1, R23.1, VBUS1.1

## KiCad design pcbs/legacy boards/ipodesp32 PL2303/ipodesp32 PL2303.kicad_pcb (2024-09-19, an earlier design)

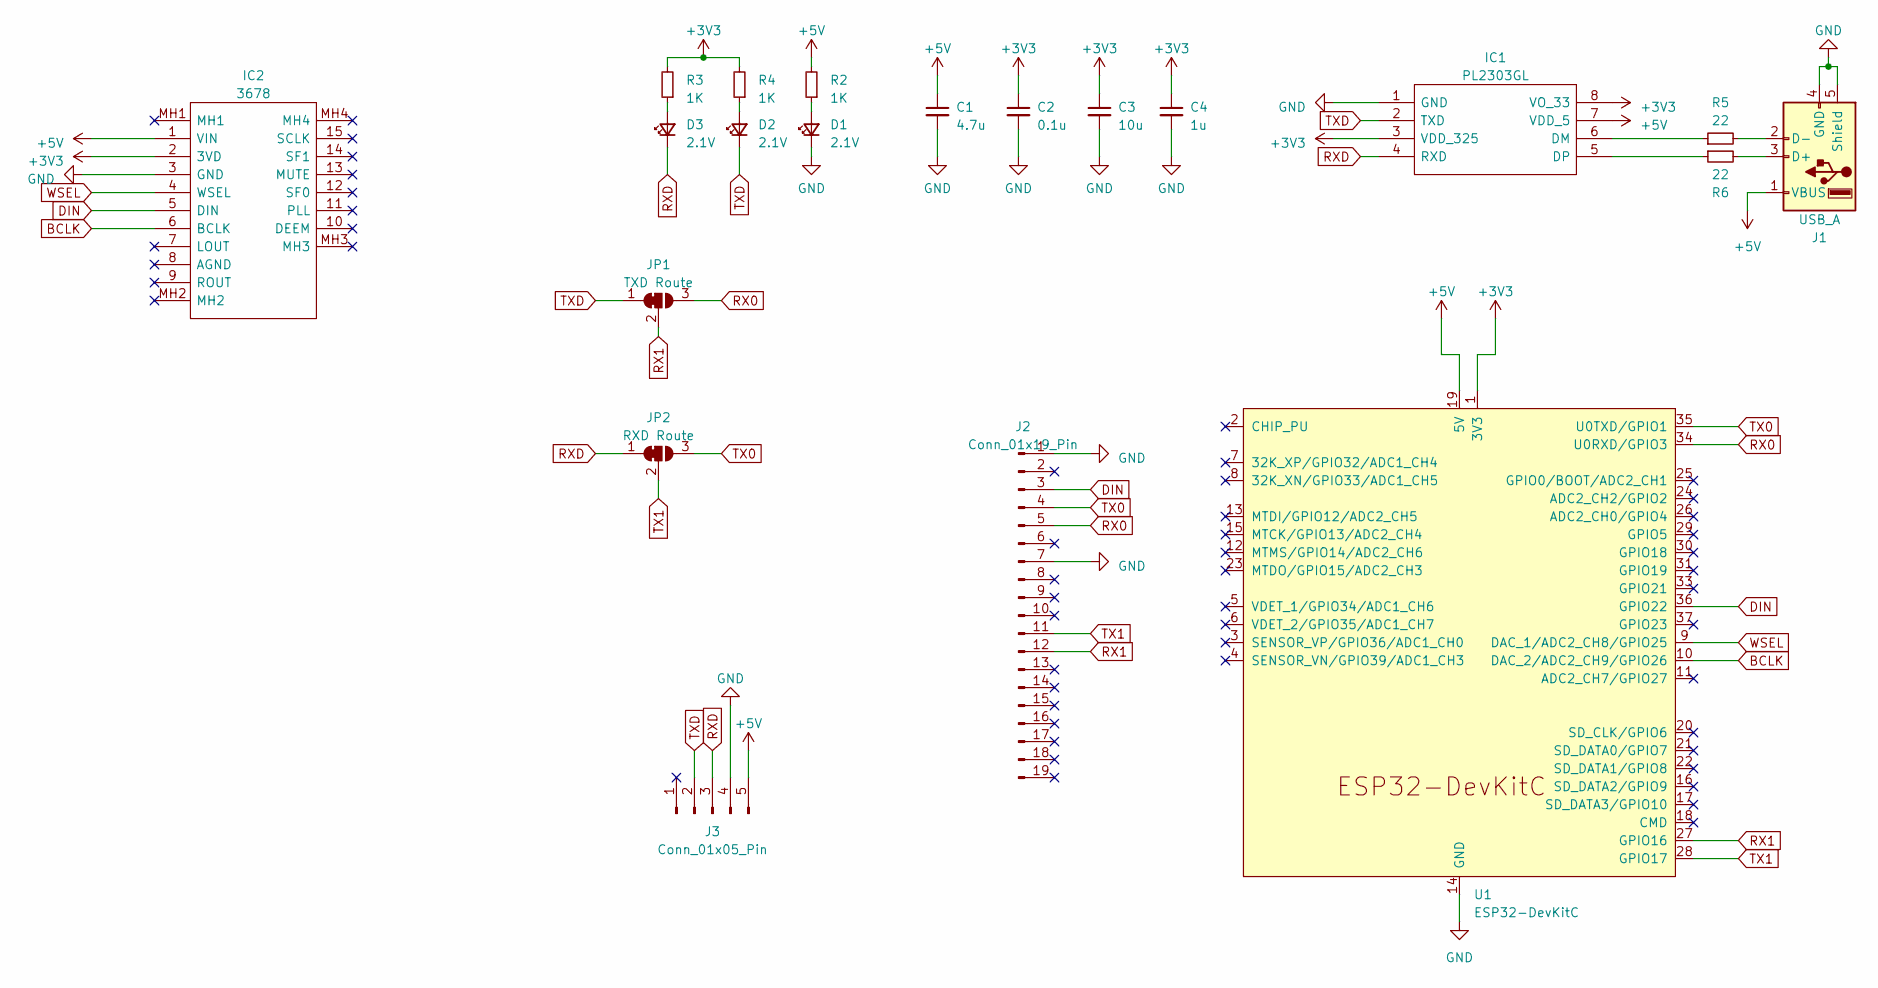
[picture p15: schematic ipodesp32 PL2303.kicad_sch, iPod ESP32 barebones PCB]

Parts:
C1: 4.7u; C_0603_1608Metric; Manufacturer_Part_Number CL10A475KP8NNNC
C2: 0.1u; C_0603_1608Metric; Manufacturer_Part_Number CC0603KRX7R7BB104
C3: 10u; C_0805_2012Metric; Manufacturer_Part_Number C0805C106K8PAC7800
C4: 1u; C_0603_1608Metric; Manufacturer_Part_Number CL10B105KP8NNNC
D1, D2, D3: 2.1V; LED_0603_1608Metric; Manufacturer_Part_Number LTST-C190GKT
IC1: PL2303GL; SOIC127P600X170-8N; Manufacturer_Part_Number PL2303GS
IC2: 3678; Manufacturer_Part_Number 3678
J1: USB_A; USB_A_CNCTech_1001-011-01101_Horizontal; Manufacturer_Part_Number 1001-011-01101
J2: Conn_01x19_Pin; PinHeader_1x19_P2.54mm_Vertical
J3: Conn_01x05_Pin; PinHeader_1x05_P2.54mm_Vertical
JP1: TXD Route; SolderJumper-3_P1.3mm_Bridged12_Pad1.0x1.5mm
JP2: RXD Route; SolderJumper-3_P1.3mm_Bridged12_Pad1.0x1.5mm
R2, R3, R4: 1K; R_0603_1608Metric; Manufacturer_Part_Number RC0603FR-071KL
R5, R6: 22; R_0603_1608Metric; Manufacturer_Part_Number RC0603FR-0722RL
U1: ESP32-DevKitC

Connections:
+3V3: C2.1, C3.1, C4.1, IC1.3 (VDD_325), IC1.8 (VO_33), IC2.2 (3VD), R3.2, R4.2, U1.1 (3V3)
+5V: C1.1, IC1.7 (VDD_5), IC2.1 (VIN), J1.1 (VBUS), J3.5, R2.2, U1.19 (5V)
BCLK: IC2.6 (BCLK), U1.10 (DAC_2/ADC2_CH9/GPIO26)
DIN: IC2.5 (DIN), J2.3, U1.36 (GPIO22)
GND: C1.2, C2.2, C3.2, C4.2, D1.1 (K), IC1.1 (GND), IC2.3 (GND), J1.4 (GND), J1.5 (Shield), J2.1, J2.7, J3.4, U1.14 (GND), U1.32 (GND), U1.38 (GND)
unnamed: D1.2 (A), R2.1
unnamed: D2.2 (A), R4.1
unnamed: D3.2 (A), R3.1
unnamed: IC1.6 (DM), R5.1
unnamed: IC1.5 (DP), R6.1
unnamed: J1.3 (D+), R6.2
unnamed: J1.2 (D-), R5.2
RX0: J2.5, JP1.3 (B), U1.34 (U0RXD/GPIO3)
RX1: J2.12, JP1.2 (C), U1.27 (GPIO16)
RXD: D3.1 (K), IC1.4 (RXD), J3.3, JP2.1 (A)
TX0: J2.4, JP2.3 (B), U1.35 (U0TXD/GPIO1)
TX1: J2.11, JP2.2 (C), U1.28 (GPIO17)
TXD: D2.1 (K), IC1.2 (TXD), J3.2, JP1.1 (A)
WSEL: IC2.4 (WSEL), U1.9 (DAC_1/ADC2_CH8/GPIO25)

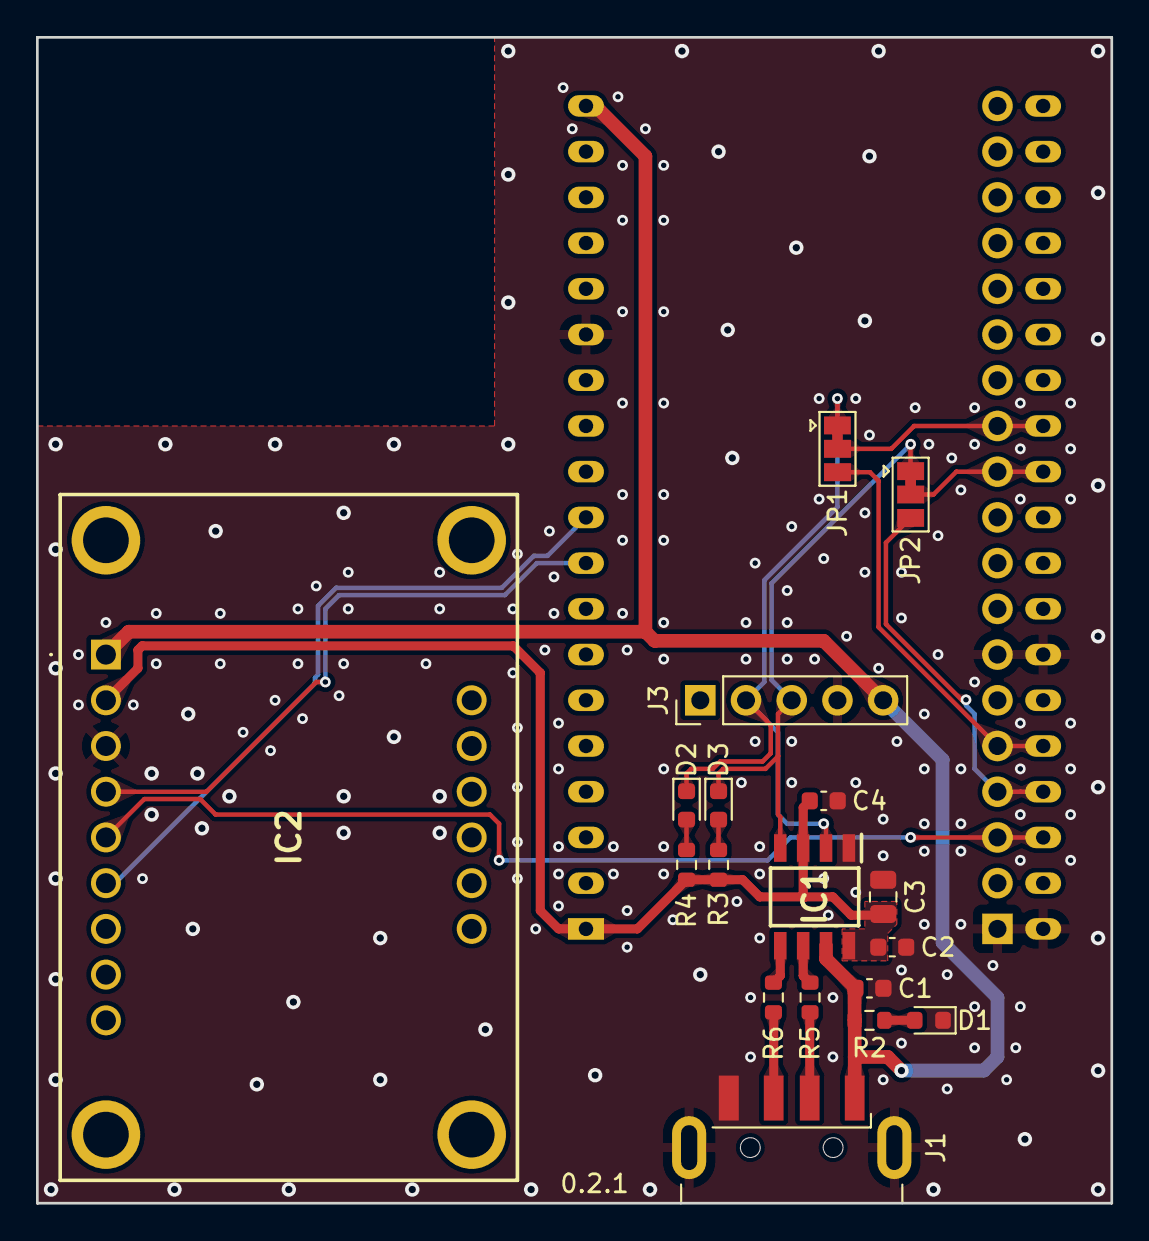
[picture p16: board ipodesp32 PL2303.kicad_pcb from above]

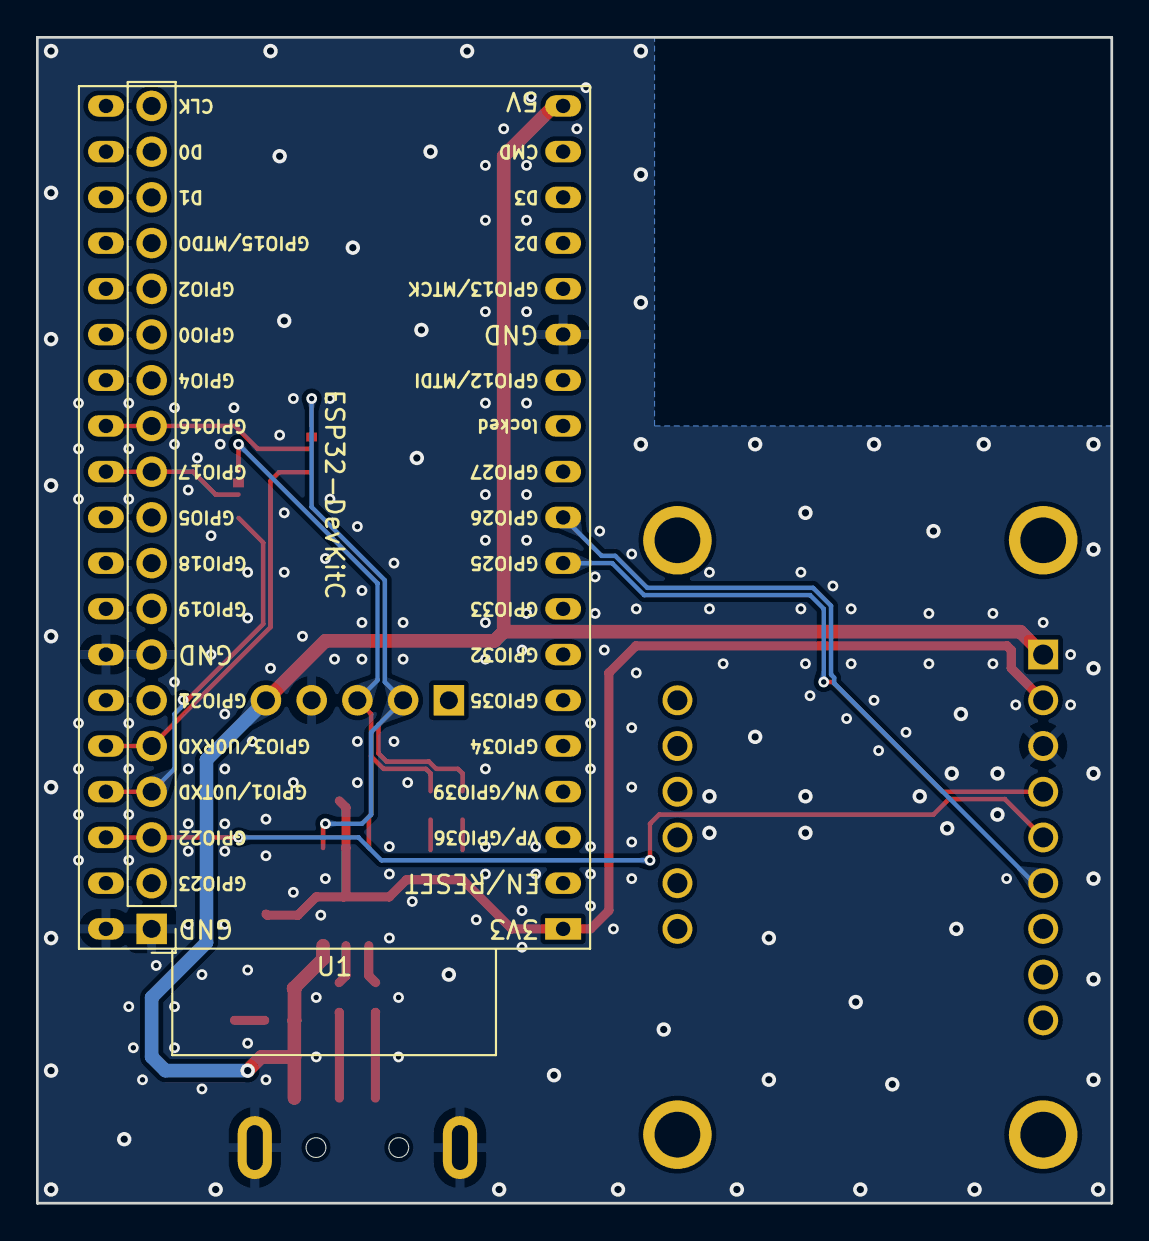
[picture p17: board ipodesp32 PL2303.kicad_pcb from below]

Board: 2 copper layers, 59.7 x 64.8 mm, 20 parts (2 on the bottom side), 19 nets.

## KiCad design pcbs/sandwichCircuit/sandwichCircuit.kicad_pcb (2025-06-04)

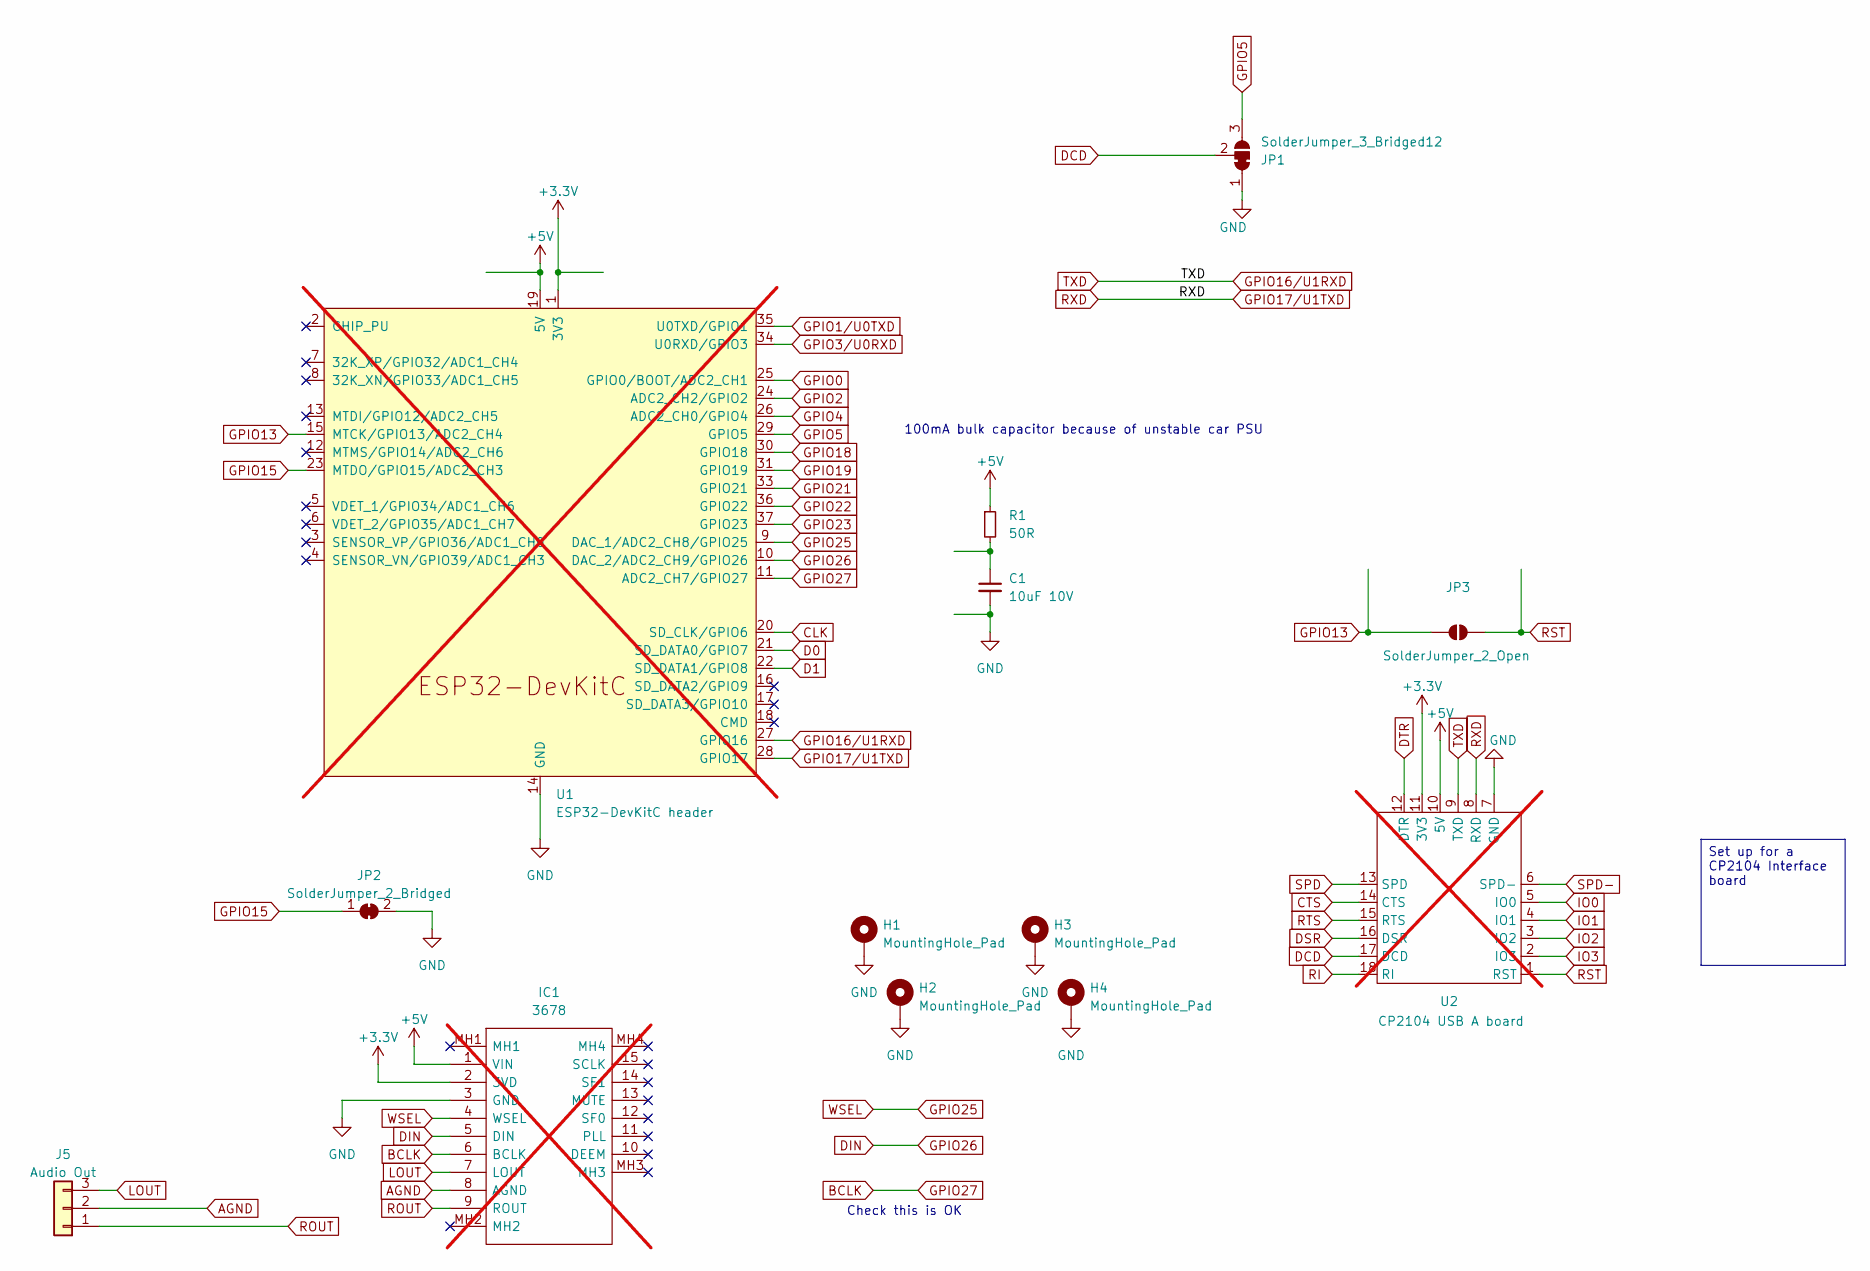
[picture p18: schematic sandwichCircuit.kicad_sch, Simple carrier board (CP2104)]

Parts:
C1: 10uF 10V; C_Radial_D5.0mm_H7.0mm_P2.00mm
H1, H2, H3, H4: MountingHole_Pad; MountingHole_3.2mm_M3_Pad_TopBottom
IC1: 3678; Manufacturer_Part_Number 3678; Mouser Part Number 485-3678; not fitted
J5: Audio Out; PinHeader_1x03_P2.54mm_Vertical
JP1: SolderJumper_3_Bridged12; SolderJumper-3_P1.3mm_Bridged12_RoundedPad1.0x1.5mm
JP2: SolderJumper_2_Bridged; SolderJumper-2_P1.3mm_Bridged_RoundedPad1.0x1.5mm
JP3: SolderJumper_2_Open; SolderJumper-2_P1.3mm_Open_RoundedPad1.0x1.5mm
R1: 50R; R_Axial_DIN0207_L6.3mm_D2.5mm_P10.16mm_Horizontal
U1: ESP32-DevKitC header; ESP32-DevKitC; not fitted
U2: CP2104 USB A board; CP2104_USB_Board; not fitted

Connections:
+3.3V: IC1.2 (3VD), U1.1 (3V3), U2.11 (3V3)
+5V: IC1.1 (VIN), R1.1, U1.19 (5V), U2.10 (5V)
AGND: IC1.8 (AGND), J5.2
BCLK: IC1.6 (BCLK), U1.11 (ADC2_CH7/GPIO27)
CLK: U1.20 (SD_CLK/GPIO6)
CTS: U2.14 (CTS)
D0: U1.21 (SD_DATA0/GPIO7)
D1: U1.22 (SD_DATA1/GPIO8)
DCD: JP1.2 (C), U2.17 (DCD)
DIN: IC1.5 (DIN), U1.10 (DAC_2/ADC2_CH9/GPIO26)
DSR: U2.16 (DSR)
DTR: U2.12 (DTR)
GND: C1.2, H1.1, H2.1, H3.1, H4.1, IC1.3 (GND), JP1.1 (A), JP2.2 (B), U1.14 (GND), U1.32 (GND), U1.38 (GND), U2.7 (GND)
GPIO0: U1.25 (GPIO0/BOOT/ADC2_CH1)
GPIO1/U0TXD: U1.35 (U0TXD/GPIO1)
GPIO2: U1.24 (ADC2_CH2/GPIO2)
GPIO3/U0RXD: U1.34 (U0RXD/GPIO3)
GPIO4: U1.26 (ADC2_CH0/GPIO4)
GPIO5: JP1.3 (B), U1.29 (GPIO5)
GPIO13: JP3.1 (A), U1.15 (MTCK/GPIO13/ADC2_CH4)
GPIO15: JP2.1 (A), U1.23 (MTDO/GPIO15/ADC2_CH3)
GPIO16/U1RXD: U1.27 (GPIO16), U2.9 (TXD)
GPIO17/U1TXD: U1.28 (GPIO17), U2.8 (RXD)
GPIO18: U1.30 (GPIO18)
GPIO19: U1.31 (GPIO19)
GPIO21: U1.33 (GPIO21)
GPIO22: U1.36 (GPIO22)
GPIO23: U1.37 (GPIO23)
GPIO25: IC1.4 (WSEL), U1.9 (DAC_1/ADC2_CH8/GPIO25)
IO0: U2.5 (IO0)
IO1: U2.4 (IO1)
IO2: U2.3 (IO2)
IO3: U2.2 (IO3)
LOUT: IC1.7 (LOUT), J5.3
unnamed: C1.1, R1.2
RI: U2.18 (RI)
ROUT: IC1.9 (ROUT), J5.1
RST: JP3.2 (B), U2.1 (RST)
RTS: U2.15 (RTS)
SPD: U2.13 (SPD)
SPD-: U2.6 (SPD-)

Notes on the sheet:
100mA bulk capacitor because of unstable car PSU
Check this is OK
Set up for a CP2104 Interface board

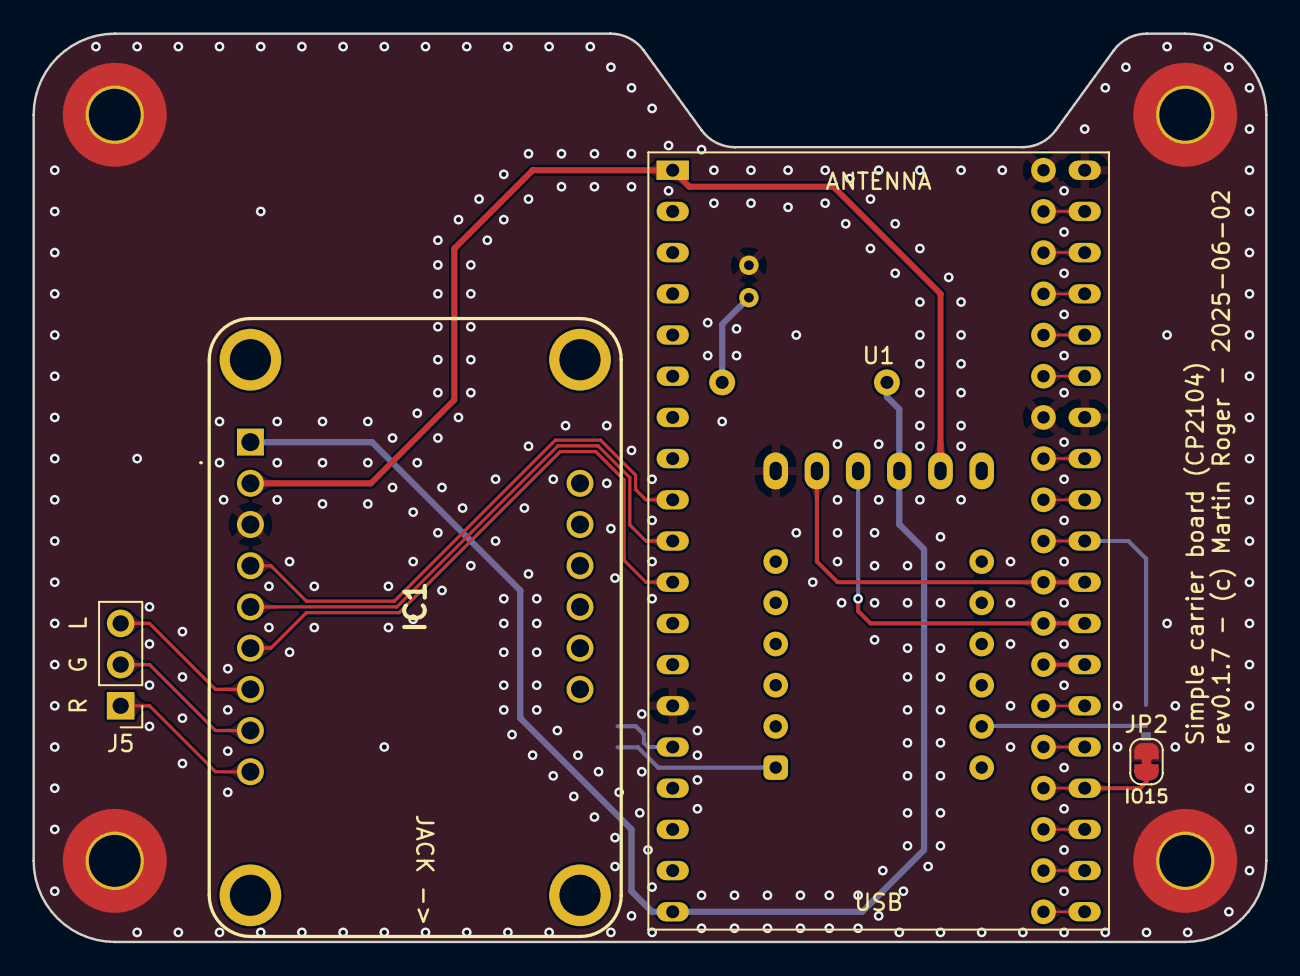
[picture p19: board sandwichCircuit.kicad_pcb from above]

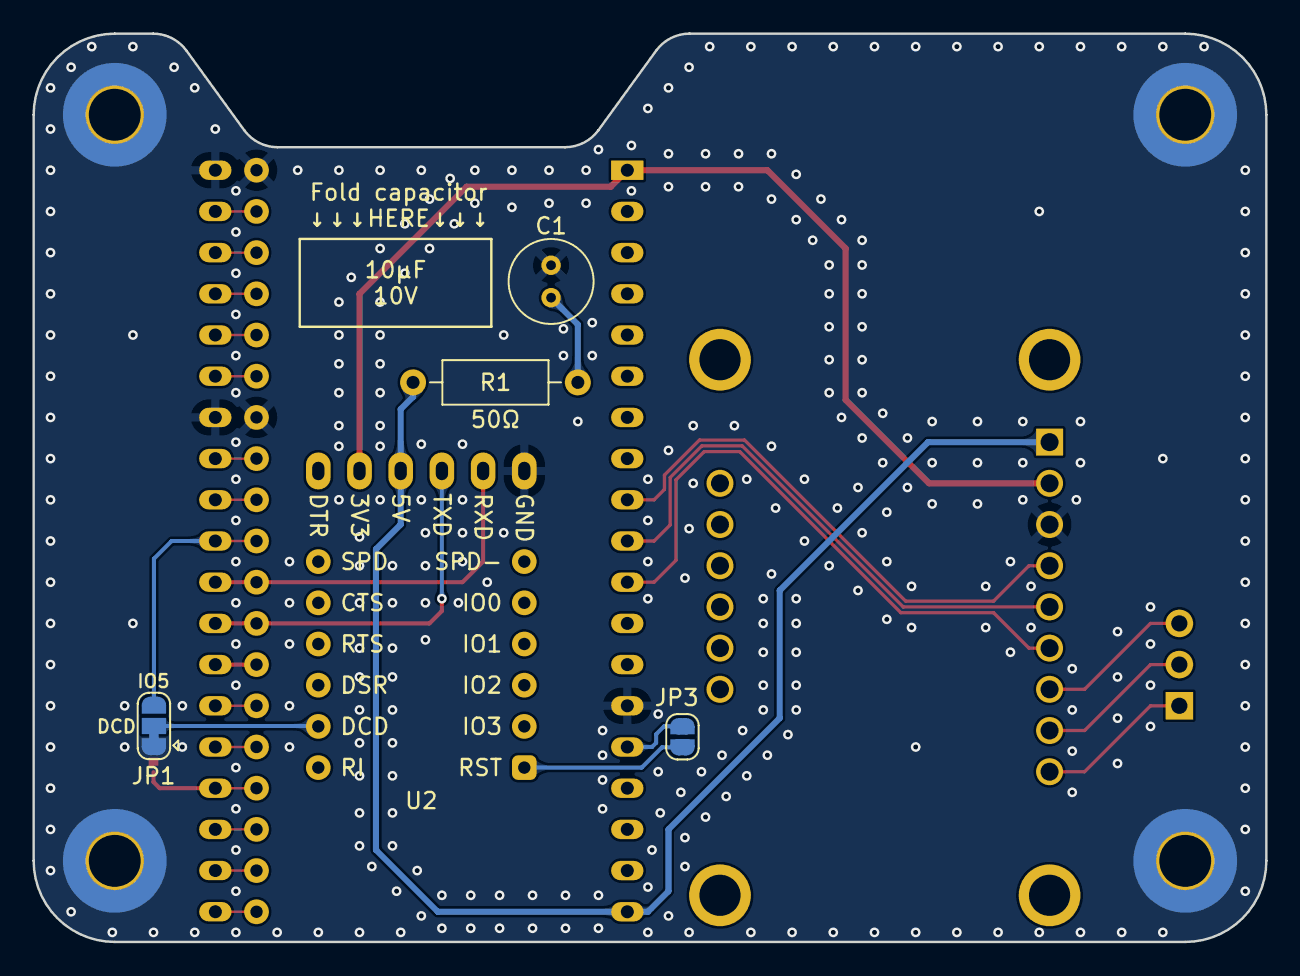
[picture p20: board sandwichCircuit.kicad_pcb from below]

Board: 2 copper layers, 76.0 x 56.0 mm, 13 parts (5 on the bottom side), 17 nets.

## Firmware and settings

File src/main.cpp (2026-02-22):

#include <Arduino.h>
#include "AudioTools.h"
#include "BluetoothA2DPSink.h"
#include "esPod.h"

#pragma region Board IO Macros
// LED Logic inversion
#ifndef INVERT_LED_LOGIC
#define INVERT_LED_LOGIC(stateBoolean) stateBoolean
#else
#undef INVERT_LED_LOGIC
#define INVERT_LED_LOGIC(stateBoolean) !stateBoolean
#endif

// DCD Logic inversion
#ifndef INVERT_DCD_LOGIC
#define INVERT_DCD_LOGIC(stateBoolean) stateBoolean
#else
#undef INVERT_DCD_LOGIC
#define INVERT_DCD_LOGIC(stateBoolean) !stateBoolean
#endif

// DCD control pin to pretend there is a physical disconnect
#if defined(ENABLE_ACTIVE_DCD) && !defined(DCD_CTRL_PIN)
#define DCD_CTRL_PIN 5
#endif
#pragma endregion

#pragma region AVRC-related FreeRTOS tasks defines
#ifndef AVRC_QUEUE_SIZE
#define AVRC_QUEUE_SIZE 32
#endif
#ifndef PROCESS_AVRC_TASK_STACK_SIZE
#define PROCESS_AVRC_TASK_STACK_SIZE 4096
#endif
#ifndef PROCESS_AVRC_TASK_PRIORITY
#define PROCESS_AVRC_TASK_PRIORITY 6
#endif
#pragma endregion

#pragma region A2DP Sink Configuration
// A2DP instance name
#ifndef A2DP_SINK_NAME
#define A2DP_SINK_NAME "espiPod"
#endif
#ifndef WS_PIN
#define WS_PIN 25
#endif
#ifndef DIN_PIN
#define DIN_PIN 26
#endif
#ifndef BCLK_PIN
#define BCLK_PIN 27
#endif

#ifdef AUDIOKIT // Using the AiThink A1S AudioKit chip
#include "AudioBoard.h"
#include "AudioTools/AudioLibs/I2SCodecStream.h"
AudioInfo info(44100, 2, 16);
DriverPins minimalPins;
AudioBoard minimalAudioKit(AudioDriverES8388, minimalPins);
I2SCodecStream i2s(minimalAudioKit);
BluetoothA2DPSink a2dp_sink(i2s);
#else // Case not using the audiokit, like Sandwich Carrier Board
I2SStream i2s;
BluetoothA2DPSink a2dp_sink;
#endif

/// @brief Data stream reader callback
/// @param data Data buffer to pass to the I2S
/// @param length Length of the data buffer
void read_data_stream(const uint8_t *data, uint32_t length)
{
	i2s.write(data, length);
}

#pragma endregion

#pragma region Helper Functions declaration
void initializeA2DPSink();
esp_err_t initializeAVRCTask();
#pragma endregion

#pragma region A2DP/AVRC callbacks declaration
void connectionStateChanged(esp_a2d_connection_state_t state, void *ptr);
void audioStateChanged(esp_a2d_audio_state_t state, void *ptr);
void avrc_rn_play_pos_callback(uint32_t play_pos);
void avrc_metadata_callback(uint8_t id, const uint8_t *text);
void playStatusHandler(PB_COMMAND playCommand);
#pragma endregion

// Declare the principal object... multiple syntaxes are available
// Autobaud syntax example
// esPod espod(1,UART1_RX,UART1_TX,0);
esPod espod(1, UART1_RX, UART1_TX, 19200);
bool pendingPlayReq = false; // Might use this to make sure play requests are not ignored.

void setup()
{

#ifdef LED_BUILTIN
	pinMode(LED_BUILTIN, OUTPUT);
	digitalWrite(LED_BUILTIN, INVERT_LED_LOGIC(LOW));
#endif

#ifdef ENABLE_ACTIVE_DCD
	pinMode(DCD_CTRL_PIN, OUTPUT);
	digitalWrite(DCD_CTRL_PIN, INVERT_DCD_LOGIC(HIGH)); // Logic is inverted
#endif

	ESP_LOGI(__func__, "setup() start");

	// Inform of possible errors that led to a reset
	ESP_LOGI("RESET", "Reset reason: %d", esp_reset_reason());

	// Publish build information
	ESP_LOGI("BUILD_INFO", "env:%s\t date: %s\t time: %s", PIOENV, __DATE__, __TIME__);
	ESP_LOGI("VERSION", "%s", VERSION_STRING);
	ESP_LOGI("BRANCH", "%s", VERSION_BRANCH);

	// Start AVRC Notifications handler
	if (initializeAVRCTask() != ESP_OK)
		esp_restart();

	// Start the A2DP Sink
	initializeA2DPSink();

	espod.attachPlayControlHandler(playStatusHandler);
	ESP_LOGI(__func__, "Waiting for peer");
	while (a2dp_sink.get_connection_state() != ESP_A2D_CONNECTION_STATE_CONNECTED)
	{
		delay(10);
	}
	delay(50);
	ESP_LOGI(__func__, "Peer connected: %s", a2dp_sink.get_peer_name());
	ESP_LOGI(__func__, "Setup finished");
}

void loop()
{
	vTaskDelay(1); // Purely out of precaution
}

#pragma region AVRC Task and Queue declaration/definition
// Metadata universal structure
struct avrcMetadata
{
	uint8_t id = 0;
	uint8_t *payload = nullptr;
};

// AVRC Queue and Task
QueueHandle_t avrcMetadataQueue;
TaskHandle_t processAVRCTaskHandle;

/// @brief Low priority task to process a queue of received metadata
/// @param pvParameters
static void processAVRCTask(void *pvParameters)
{
	avrcMetadata incMetadata; // Incoming metadata (pointer to payload)

#ifdef STACK_HIGH_WATERMARK_LOG
	UBaseType_t uxHighWaterMark;
	UBaseType_t minHightWaterMark = PROCESS_AVRC_TASK_STACK_SIZE;
#endif

	// Main loop
	while (true)
	{
// Stack high watermark logging
#ifdef STACK_HIGH_WATERMARK_LOG
		uxHighWaterMark = uxTaskGetStackHighWaterMark(NULL);
		if (uxHighWaterMark < minHightWaterMark)
		{
			minHightWaterMark = uxHighWaterMark;
			ESP_LOGI("HWM", "Process AVRC Task High Watermark: %d, used stack: %d", minHightWaterMark,
					 PROCESS_AVRC_TASK_STACK_SIZE - minHightWaterMark);
		}
#endif
		// Check incoming metadata in queue, block indefinitely if there is nothing
		if (xQueueReceive(avrcMetadataQueue, &incMetadata, portMAX_DELAY) == pdTRUE)
		{
			if (incMetadata.payload != nullptr)
			{
				// Start processing
				switch (incMetadata.id)
				{
				case ESP_AVRC_MD_ATTR_ALBUM:

					espod.updateAlbumName((char *)incMetadata.payload);
					break;

				case ESP_AVRC_MD_ATTR_ARTIST:
					espod.updateArtistName((char *)incMetadata.payload);
					break;

				case ESP_AVRC_MD_ATTR_TITLE: // Title change triggers the NEXT track if unexpected
					espod.updateTrackTitle((char *)incMetadata.payload);
					break;

				case ESP_AVRC_MD_ATTR_PLAYING_TIME:
					espod.updateTrackDuration(atoi((char *)incMetadata.payload));
					break;
				}

				// End Processing, deallocate memory
				free(incMetadata.payload);
				incMetadata.payload = nullptr;
			}
		}
	}
}
#pragma endregion

#pragma region Helper Function Definitions

/// @brief Configures the CODEC or DAC and starts the A2DP Sink
void initializeA2DPSink()
{
#ifdef AUDIOKIT
	minimalPins.addI2C(PinFunction::CODEC, 32, 33);
	minimalPins.addI2S(PinFunction::CODEC, 0, BCLK_PIN, WS_PIN, DIN_PIN, 35);
	// a2dp_sink.set_stream_reader(read_data_stream, false); // Might need commenting out
	auto cfg = i2s.defaultConfig();
	cfg.copyFrom(info);
	i2s.begin(cfg);
#else
	a2dp_sink.set_stream_reader(read_data_stream, false);
	auto cfg = i2s.defaultConfig(TX_MODE);
	cfg.pin_ws = WS_PIN;
	cfg.pin_data = DIN_PIN;
	cfg.pin_bck = BCLK_PIN;
	cfg.sample_rate = 44100;
	cfg.i2s_format = I2S_LSB_FORMAT;
	i2s.begin(cfg);
#endif

	a2dp_sink.set_auto_reconnect(true, 10000);
	a2dp_sink.set_on_connection_state_changed(connectionStateChanged);
	a2dp_sink.set_on_audio_state_changed(audioStateChanged);
	a2dp_sink.set_avrc_metadata_callback(avrc_metadata_callback);
	a2dp_sink.set_avrc_metadata_attribute_mask(ESP_AVRC_MD_ATTR_TITLE | ESP_AVRC_MD_ATTR_ARTIST |
											   ESP_AVRC_MD_ATTR_ALBUM | ESP_AVRC_MD_ATTR_PLAYING_TIME);
	a2dp_sink.set_avrc_rn_play_pos_callback(avrc_rn_play_pos_callback, 1);

	a2dp_sink.start(A2DP_SINK_NAME);

	ESP_LOGI(__func__, "a2dp_sink started: %s", A2DP_SINK_NAME);
	delay(5);
}

/// @brief Initializes the AVRC metadata queue, and attempts to start the
/// related task
/// @return ESP_FAIL if the queue or task could not be created, ESP_OK otherwise
esp_err_t initializeAVRCTask()
{
	avrcMetadataQueue = xQueueCreate(AVRC_QUEUE_SIZE, sizeof(avrcMetadata));
	if (avrcMetadataQueue == nullptr)
	{
		ESP_LOGE(__func__, "Failed to create metadata queue");
		return ESP_FAIL;
	}

	xTaskCreatePinnedToCore(processAVRCTask, "processAVRCTask", PROCESS_AVRC_TASK_STACK_SIZE, NULL,
							PROCESS_AVRC_TASK_PRIORITY, &processAVRCTaskHandle, ARDUINO_RUNNING_CORE);
	if (processAVRCTaskHandle == nullptr)
	{
		ESP_LOGE(__func__, "Failed to create processAVRCTask");
		return ESP_FAIL;
	}

	return ESP_OK;
}
#pragma endregion

#pragma region A2DP/AVRC callbacks Definitions
/// @brief Callback on changes of A2DP connection and AVRCP connection. On
/// disconnect the esPod becomes silent.
/// @param state New state passed by the callback.
/// @param ptr Not used.
void connectionStateChanged(esp_a2d_connection_state_t state, void *ptr)
{
	switch (state)
	{
	case ESP_A2D_CONNECTION_STATE_CONNECTED:
		ESP_LOGD(__func__, "ESP_A2D_CONNECTION_STATE_CONNECTED, espod enabled");
		espod.disabled = false;
		// Meant to pre-fetch playing status
		ESP_LOGI(__func__, "Attempting to send play request.");
		a2dp_sink.play();
#ifdef LED_BUILTIN
		digitalWrite(LED_BUILTIN, INVERT_LED_LOGIC(HIGH));
#endif
		break;
	case ESP_A2D_CONNECTION_STATE_DISCONNECTED:
		ESP_LOGD(__func__, "ESP_A2D_CONNECTION_STATE_DISCONNECTED, espod disabled");
		espod.resetState();
		espod.disabled = true;
#ifdef LED_BUILTIN
		digitalWrite(LED_BUILTIN, INVERT_LED_LOGIC(LOW));
#endif
		break;
	}
#ifdef ENABLE_ACTIVE_DCD
	digitalWrite(DCD_CTRL_PIN, INVERT_DCD_LOGIC(espod.disabled)); // Logic inversion by MACRO
#endif
}

/// @brief Callback for the change of playstate after connection. Aligns the
/// state of the esPod to the state of the phone. Play should be called by the
/// espod interaction
/// @param state The A2DP Stream to align to.
/// @param ptr Not used.
void audioStateChanged(esp_a2d_audio_state_t state, void *ptr)
{
	switch (state)
	{
	case ESP_A2D_AUDIO_STATE_STARTED:
		espod.play(true);
		break;
	case ESP_A2D_AUDIO_STATE_REMOTE_SUSPEND:
		espod.pause(true);
		break;
		// case ESP_A2D_AUDIO_STATE_STOPPED:
		//  espod.stop();
		// 	break;
	}
}

/// @brief Play position callback returning the ms spent since start on every
/// interval - normally 1s
/// @param play_pos Playing Position in ms
void avrc_rn_play_pos_callback(uint32_t play_pos)
{
	espod.updatePlayPosition(play_pos);
	ESP_LOGV(__func__, "PlayPosition called");
}

/// @brief Catch callback for the AVRC metadata. There can be duplicates !
/// @param id Metadata attribute ID : ESP_AVRC_MD_ATTR_xxx
/// @param text Text data passed around, sometimes it's a uint32_t disguised as
/// text
void avrc_metadata_callback(uint8_t id, const uint8_t *text)
{
	// Guard checks
	if (text == NULL)
	{
		ESP_LOGW(__func__, "Received empty pointer for ID %d", id);
		return;
	}
	if ((id != ESP_AVRC_MD_ATTR_PLAYING_TIME) && (text[0] == '\0'))
	{
		ESP_LOGW(__func__, "Empty string received for ID %d", id);
		return;
	}

	avrcMetadata incMetadata;
	incMetadata.id = id;
	incMetadata.payload = (uint8_t *)strdup((const char *)text);

	if (incMetadata.payload == nullptr)
	{
		ESP_LOGE(__func__, "Memory allocation failed for metadata");
		return;
	}

	if (xQueueSend(avrcMetadataQueue, &incMetadata, 0) != pdTRUE)
	{
		ESP_LOGW(__func__, "Metadata queue full, discarding metadata");
		free(incMetadata.payload);
	}
}

/// @brief Callback function that passes intended playback operations from the
/// esPod to the A2DP player (i.e. the phone)
/// @param playCommand
void playStatusHandler(PB_COMMAND playCommand)
{
	switch (playCommand)
	{
	case PB_CMD_STOP:
		a2dp_sink.stop();
		ESP_LOGD(__func__, "A2DP_STOP");
		break;
	case PB_CMD_PLAY:
		a2dp_sink.play();
		ESP_LOGD(__func__, "A2DP_PLAY");
		break;
	case PB_CMD_PAUSE:
		a2dp_sink.pause();
		ESP_LOGD(__func__, "A2DP_PAUSE");
		break;
	case PB_CMD_PREVIOUS_TRACK:
		a2dp_sink.previous();
		ESP_LOGD(__func__, "A2DP_REWIND");
		break;
	case PB_CMD_NEXT_TRACK:
		a2dp_sink.next();
		ESP_LOGD(__func__, "A2DP_NEXT");
		break;
	case PB_CMD_NEXT:
		a2dp_sink.next();
		ESP_LOGD(__func__, "A2DP_NEXT");
		break;
	case PB_CMD_PREV:
		a2dp_sink.previous();
		ESP_LOGD(__func__, "A2DP_PREV");
		break;
	}
}

#pragma endregion

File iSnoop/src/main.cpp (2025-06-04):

#include <Arduino.h>

#include "snooper.h"

HardwareSerial RXUart_1(1);
HardwareSerial RXUart_2(2);

#ifndef UART1_RX
#define UART1_RX 18
#endif

#ifndef UART1_TX
#define UART1_TX 19
#endif

#ifndef UART2_RX
#define UART2_RX 16
#endif

#ifndef UART2_TX
#define UART2_TX 17
#endif

// snooper espod(ipodSerial);
snooper UART1(RXUart_1, "UART1");
snooper UART2(RXUart_2, "UART2");

#ifndef IPOD_DETECT
#define IPOD_DETECT 4
#endif


#pragma region Helper Functions declaration

void initializeSerial();
#pragma endregion


void setup()
{
	initializeSerial();
	UART1.detectPin = IPOD_DETECT;
	UART2.detectPin = IPOD_DETECT;
	ESP_LOGI("SETUP", "Setup finished");
}

void loop()
{
}


/// @brief Sets up and starts the appropriate Serial interface
void initializeSerial()
{
	Serial.begin(115200);
	RXUart_1.setPins(UART1_RX, UART1_TX);
	RXUart_2.setPins(UART2_RX, UART2_TX);
	RXUart_1.setRxBufferSize(1024);
	RXUart_1.setTxBufferSize(1024);
	RXUart_2.setRxBufferSize(1024);
	RXUart_2.setTxBufferSize(1024);
	RXUart_1.begin(19200);
	RXUart_2.begin(19200);
}

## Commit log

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2024-05-23 Extension to two-track mind
    - Next/Previous didn't seem to work because of the number of tracks being returned as only 1 -> the car would default to always requesting Previous
    - Suspicion that the Title metadata is sometimes a bit slow to come in. Decision to pull it actively after an AVRC next/previous command using esp_avrc_ct_send_metadata_cmd
    - Introduced a flip-flopping byte called _currentTrackIndex that keeps alternating between the two, should cast the same data but allow some emulation at the car level
    [main.cpp]
2024-05-24 Increasing number of total tracks
    Introduced enums to control PB status, commands, and DB categories
    Current track index is now something that can go up to 16000
    Current track index is not flipflopping but now is increasing
    Receiving metadata is considered a track change. System will notify if possible.
    [main.cpp]
2024-05-24 Serial buffer resizing corrections
    Cause I can't read the manual, visibly
    [main.cpp]
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2024-05-25 Started the move to audiotools, but compile size is too big
    [main.cpp]
2024-05-25 Update for external DAC, size still too big
    [main.cpp]
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2024-05-27 Code clean-up
    Private properties are now the only ones underscored
    Handshake boolean removed - not used
    Notification states added
    Introduced playPosition public property
    Adjusted start and reset states for espod
    [main.cpp]
2024-06-03 PL2303 board release
    [ipodesp32 PL2303.kicad_pcb, ipodesp32 PL2303.kicad_sch, ipodesp32 PL2303.sch]
2024-06-03 Layout tracing
    [ipodesp32 PL2303.kicad_pcb]
2024-06-04 Update to PCB with integrated PL2303
    [ipodesp32 PL2303.kicad_pcb, ipodesp32 PL2303.kicad_sch]
2024-06-04 PCBWay Quote
    [ipodesp32 PL2303.kicad_pcb, ipodesp32 PL2303.kicad_sch]
2024-07-09 Serial and PCBWay bom
    [iPodEsp32_BOM_PCBWay.xlsx]
2024-07-09 Back to Main Serial
    resetState function is a one-way street once disabled
    [main.cpp]
2024-07-16 Corrected GS to GL on PL2303
    [ipodesp32 PL2303.kicad_pcb, ipodesp32 PL2303.kicad_sch]
2024-08-27 Update main.cpp
    resetState before bluetooth disable.
    [main.cpp]
2024-08-28 Trailing track metadata, cursor and track select clean-up
    - Added prevTrackDuration in esPod.h to also quickly return previous track duration
    - Metadata returning functions of L0x04 now have the option to return the previous data that was previously loaded, without needing a track change
    - A2DP NEXT and PREV are now fired up _after_ the cursoring and data fields pass-over, to avoid interruption by the metadata callback during the copy
    - cursoring around trackList is hopefully a little bit cleaner to read now
    - Removed condition that if there was a new track selection and it is not playing, we would set it to a "next track". Simply start playback if it was not active, and then analyse if it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
    [main.cpp]
2024-08-28 Update esPod.cpp
    Edge case of the first track to play and making sure that metadata is pulled in.
2024-09-03 Preparation work for better metadata handling
    - Overloaded L0x04_0x01 iPodAck function to also be able to do CmdPending
    - Added marker byte for which is the command with a pending track change
    - Added timeout macro value, and timestamp for trackChange
2024-09-04 First metadata handler rewrite
    Based on title string update
    Features also a failsafe in the refresh() method
    Unexpected changes of metadata require all three fields to update to fire a track notification.
    TODO : flow diagram
    [main.cpp]
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2024-09-12 Line 1071
    - started clean-up of _debugSerial outputs
    - new Metadata concept
    - new Play Current Selection concept
2024-09-13 Clean-up and debug complete
    - TrackDuration integrated to metadata despamming and management
    - removal of unused properties from espod class
    - Refactoring and realigning of PB Control on the index-based track change lingo commands
    - Removal of all mentions to DEBUG_MODE and DUMP_MODE in Packet Disneyland
2024-09-14 Bug Correction #7
    Hazardous tempTrackIndex called in PlayControl led to loop situations.
    Attempt to fix #7
    Still need to figure out if it is sending Prev or Previous Track to rewind over PlayControl
2024-09-14 Bug #7 mitigation part deux
    - Pre-initialises the trackList to a linear increasing list of trackIndex
    - Removes the PlayControl track change management for PREV and PREV_TRACK
2024-09-16 Accelerating play pos notif
    Also muting when there is a trackChangeAckPending to avoid confusion
    [main.cpp]
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2024-11-18 SD Update and ESP_LOGx implemented
    Still missing logging vprintf
    [main.cpp]
2024-11-20 Partial functionality, issues with other libraries
    Creates issues with other libraries when TAG is defined. Functionality is hit and miss.
    [main.cpp]
2024-11-26 Clean build point with only SD Update
    - SD Log has issues with Log level set
    - Probable necessity to raise to a different ESP IDF (more recent)
    [main.cpp]
2024-11-27 LastConnected ticker correction
    Removing divisions by 1000 and aligning with reset case
    [main.cpp]
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2024-11-30 Working version
    - Corrected issue with double assignments of GPIOs -> uses explicit pins declaration
    - Aligned data type for lastConnected to ``unsigned long``
    [main.cpp]
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2025-02-03 Moving AVRC Metadata processing to low prio task
    AVRC callback is short (memory allocation), now introducing processAVRCTask for async processing !
    [main.cpp]
2025-02-04 Heap errors protection
    Don't delete null pointers memory slots...
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2025-02-05 Prohibited load solution
    - Timer now passes pointer to the class instance instead of some sub properties.
    - Still maintaining queue and async task to avoid calling a non-ISR queuing directly in timer.
    - Appears to resolve #29
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2025-02-09 Missed first shake of hand patch
    Correcting the case where the mini doesn't receive the first request capability and fails to start the handshake.
2025-02-10 Corrections and AVRC Macro
    [main.cpp]
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2025-02-17 Reset reason + Reassignment on ESP_LOGI tags
    [main.cpp]
2025-02-18 Progress sandwhich board
    [sandwichCircuit.kicad_pcb, sandwichCircuit.kicad_sch]
2025-02-19 Simplified footprints, schematic revisited
    [sandwichCircuit.kicad_pcb, sandwichCircuit.kicad_sch]
2025-02-20 v0.1 of simple carrier board
    [sandwichCircuit.kicad_pcb, sandwichCircuit.kicad_sch]
2025-02-22 A1S board start
    [CP2102.kicad_sch, a1s-mini.kicad_pcb, a1s-mini.kicad_sch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]
2025-02-23 Starting A1S Mini, teardrops on sandwhich
    [CP2102.kicad_sch, USBC.kicad_sch, a1s-mini.kicad_pcb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]
2025-02-23 Corrections and PCB layout
    [CP2102.kicad_sch, USBC.kicad_sch, a1s-mini.kicad_pcb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]
2025-02-24 Progress on differential routing
    [a1s-mini.kicad_pcb]
2025-02-25 Advancing routing
    [a1s-mini.kicad_pcb]
2025-02-26 Timeout reduction, small correction
    Timeout reduced to 2500ms
    Logging message correction
    v0.4.3
    [main.cpp]
2025-02-26 Sandwich board 0.1.1
    [sandwichCircuit.kicad_pcb, sandwichCircuit.kicad_sch]
2025-02-26 Restart A1S mini
    [CP2102.kicad_sch, USBC.kicad_sch, a1s-mini.kicad_pcb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]
2025-02-27 Additional VBus capacitor
    Also making sure that the CP2102N is not bus-powered, but self-powered
    [a1s-mini.kicad_pcb, a1s-mini.kicad_sch]
2025-02-28 PCB layout update
    [CP2102.kicad_sch, USBC.kicad_sch, a1s-mini.kicad_pcb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]
2025-03-01 A1S Mini quote PCBWay
    [CP2102.kicad_sch, USBC.kicad_sch, a1s-mini.kicad_pcb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]
2025-03-01 Pin corrections for I2S
    [main.cpp]
2025-03-01 Corrections to Serial and Pin
    - Stop using Serial2 and reallocate UART1 for devkit based solution
    - Still some issues with stream write ? Need to use callback ?
    [main.cpp]
2025-03-01 Reducing popping noises on pause
    Only valid for options with external DACs. Uses the stream reader callback
    [main.cpp]
2025-03-01 Sandwich board adjustments
    [sandwichCircuit.kicad_pcb, sandwichCircuit.kicad_sch]
2025-03-02 TopHat board start
    [CP2102.kicad_sch, USBC.kicad_sch, hautDeForme.kicad_pcb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]
2025-03-03 Haut de forme v0.1
    [CP2102.kicad_sch, USBC.kicad_sch, hautDeForme.kicad_pcb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]
2025-03-03 Repaired some references to 3D models
    [hautDeForme.kicad_pcb]
2025-03-03 3D checks
    [hautDeForme-hautDeForme.step, hautDeForme.FCStd, hautDeForme.kicad_pcb]
2025-03-03 Haut de Forme sending to PCBWay v0.1
    [hautDeForme.kicad_pcb]
2025-03-06 Sandwich board correction
    [sandwichCircuit.kicad_pcb]
2025-03-11 Projects consistency update
    [CP2102.kicad_sch, USBC.kicad_sch, a1s-mini.kicad_pcb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]
2025-03-18 Update SCB
    Updated SCB :
    - Upper pins of CP2104 moved about 0.5mm up
    - CP2104 reset is now available on GPIO 13
    [sandwichCircuit.kicad_pcb, sandwichCircuit.kicad_sch]
2025-03-18 Updates to include resettable UART1 if available
    [main.cpp]
2025-03-19 Adding bulk 5V capacitor to SCB
    [sandwichCircuit.kicad_pcb, sandwichCircuit.kicad_sch]
2025-03-19 Image and 3D objects updates
    [a1s-mini.kicad_pcb]
2025-03-29 ESP32 A1S outline change
    [a1s-mini.kicad_pcb]
2025-03-30 A1S mini corrected, v0.3.0
    [CP2102.kicad_sch, USBC.kicad_sch, a1s-mini.kicad_pcb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]
2025-03-30 Better 0.3.0 for A1S mini, PCB way quotation
    [a1s-mini.kicad_pcb]
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2025-04-17 PCM5102A implementation (initial schematics)
    [AiO-i2s-DAC.kicad_sch]
2025-04-17 BOM pre-fill, no layout
    [AiO-i2s-DAC.kicad_sch]
2025-05-18 Exposing DCD, 3V3 and 5V in schematic
    [AiO-i2s-DAC.kicad_sch, CP2102.kicad_sch, USBC.kicad_sch]
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2025-05-21 Footprints update
    [AiO-i2s-DAC.kicad_pcb, AiO-i2s-DAC.kicad_sch]
2025-05-25 Moving audio jack and generating step files
    [a1s-mini.kicad_pcb]
2025-05-26 CP2102 instead of CP2102N
    Moving some components to CP2102 non N
    [AiO-i2s-DAC.kicad_pcb, AiO-i2s-DAC.kicad_sch, CP2102-GM.kicad_sch]
2025-05-26 Move to CP2102 non N
    [CP2102-GM.kicad_sch, USBC.kicad_sch, a1s-mini.kicad_pcb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]
2025-06-04 Task control and major refactor (#40)
    * Update platformio.ini
    * Update platformio.ini
    * Clean-up and audioKit.json
    * RX Task and basic utilities
    - Completed _rxTask write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
    [AiO-i2s-DAC.kicad_pcb, AiO-i2s-DAC.kicad_sch, AiO-i2s-DAC.sch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]
2025-06-04 Rebase from main
    [AiO-i2s-DAC.kicad_pcb]
2025-06-04 Clean up of PCB and schematic
    [AiO-i2s-DAC.kicad_pcb, AiO-i2s-DAC.kicad_sch, CP2102-GM.kicad_sch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]
2025-08-31 Adding equivalent JLCPCB values
    [AiO-i2s-DAC.kicad_pcb, AiO-i2s-DAC.kicad_sch, CP2102-GM.kicad_sch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]
2025-09-01 LCSC BOM Preparation
    [AiO-i2s-DAC.kicad_pcb, AiO-i2s-DAC.kicad_sch, CP2102-GM.kicad_sch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]
2025-09-28 Added board properties
    [AiO-i2s-DAC.kicad_pcb]
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2025-09-30 Build prep
    [AiO-i2s-DAC.kicad_pcb, AiO-i2s-DAC.kicad_sch, CP2102-GM.kicad_sch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]
2025-10-05 UART0 LEDs correction
    [AiO-i2s-DAC.kicad_pcb, AiO-i2s-DAC.kicad_sch, CP2102-GM.kicad_sch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]
2025-10-05 Collateral update of A1S mini (TX LEDs fix)
    [CP2102-GM.kicad_sch, CP2102.kicad_sch, USBC.kicad_sch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]
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2026-02-17 Legacy PCB relocation
    [CP2102-GM.kicad_sch, CP2102.kicad_sch, USBC.kicad_sch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]
2026-02-22 Trying to catch a metadata bug
    [main.cpp]
2026-02-22 Resolves hazardous metadata reception
    [main.cpp]
